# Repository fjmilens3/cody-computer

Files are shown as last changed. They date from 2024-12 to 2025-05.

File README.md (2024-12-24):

# The Cody Computer Project

This repository contains the design files and source code for the Cody 
Computer, an 8-bit home computer built around the WDC 65C02 and the 
Parallax Propeller.

Each subdirectory contains a portion of the design:

- `KiCad` contains the design files for the Cody Computer's electronics.
- `OpenSCAD` contains the design files for the Cody Computer's printable parts.
- `PDF` contains generated PDFs of the KiCad schematics.
- `Spin` contains the Propeller `.spin` files for the Propeller's firmware.
- `STL` contains the generated STL files suitable for slicing and printing.
- `Tass` contains the `64tass` assembly files for Cody BASIC and demo programs.
- `CodyBASIC` contains some sample Cody BASIC programs used for demo purposes.

All design files and sources are released under the GPL version 3. A mention
of the Cody Computer in any derived works is also appreciated.

__The Cody Computer Book__ detailing the project is not released under the GPL
but may be freely distributed. Visit 
[www.codycomputer.org](https://www.codycomputer.org) for more information.

If any technical issues or inaccuracies are found in any of the material,
please reach out to the author or raise an issue on GitHub.

Frederick John Milens III \
December 2024

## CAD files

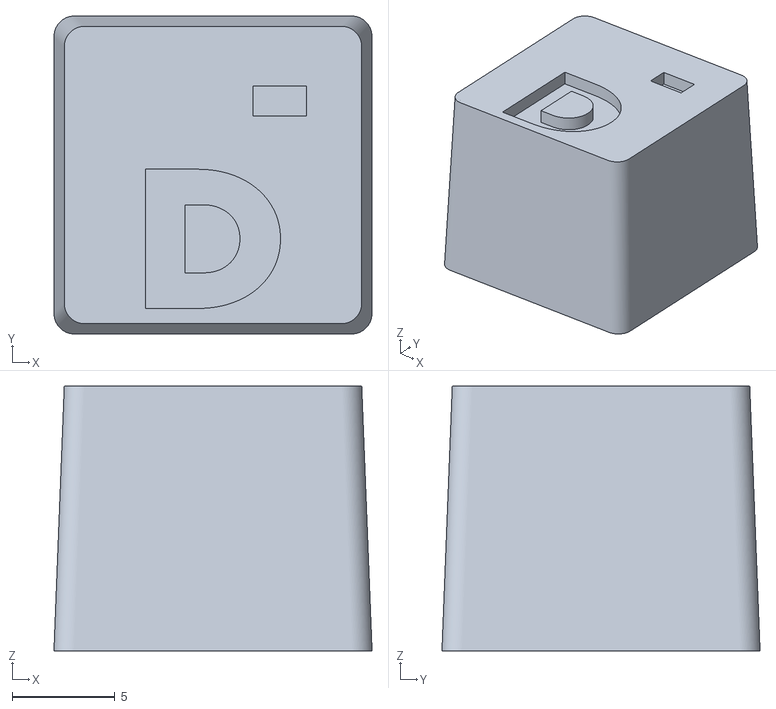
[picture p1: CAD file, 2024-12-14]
STL/KeycapD.stl
15.5 x 15.5 x 12.9

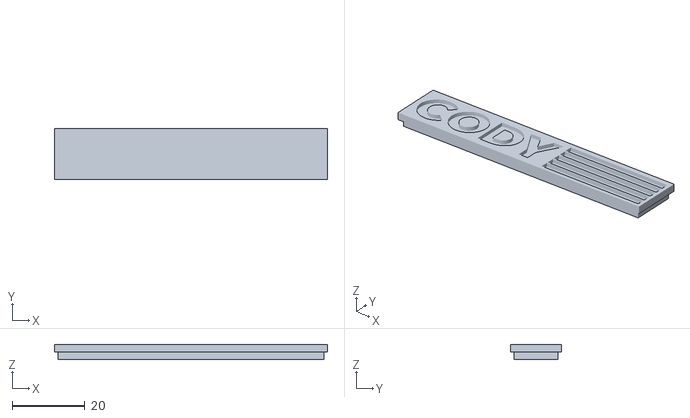
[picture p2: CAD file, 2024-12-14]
STL/CaseBadge.stl
75.0 x 14.0 x 4.00

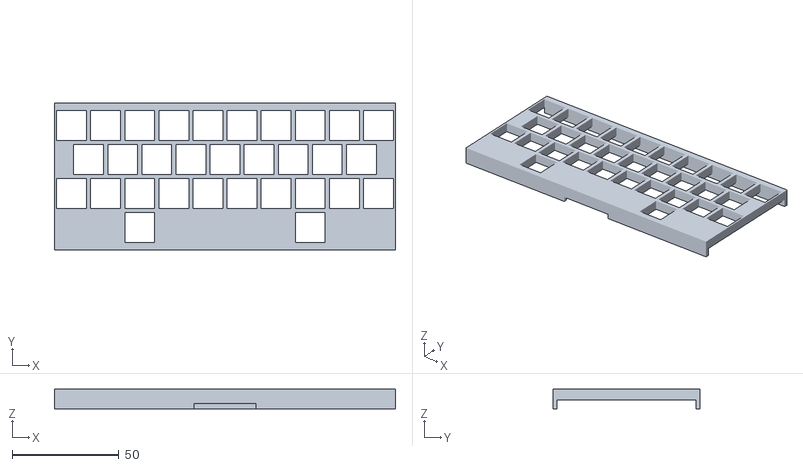
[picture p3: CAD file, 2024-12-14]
STL/KeyboardPlate.stl
160.0 x 69.0 x 9.20

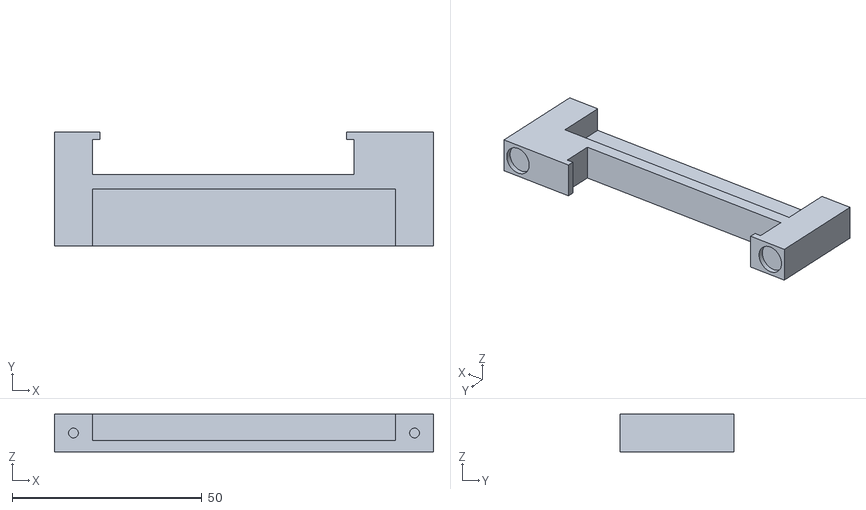
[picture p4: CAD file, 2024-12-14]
STL/KeyboardBracketWithoutHoles.stl
100.0 x 30.0 x 10.0

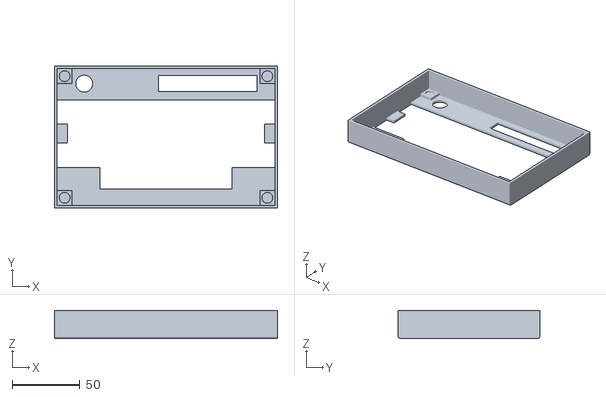
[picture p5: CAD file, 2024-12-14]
STL/CaseTop.stl
165.0 x 105.0 x 21.0

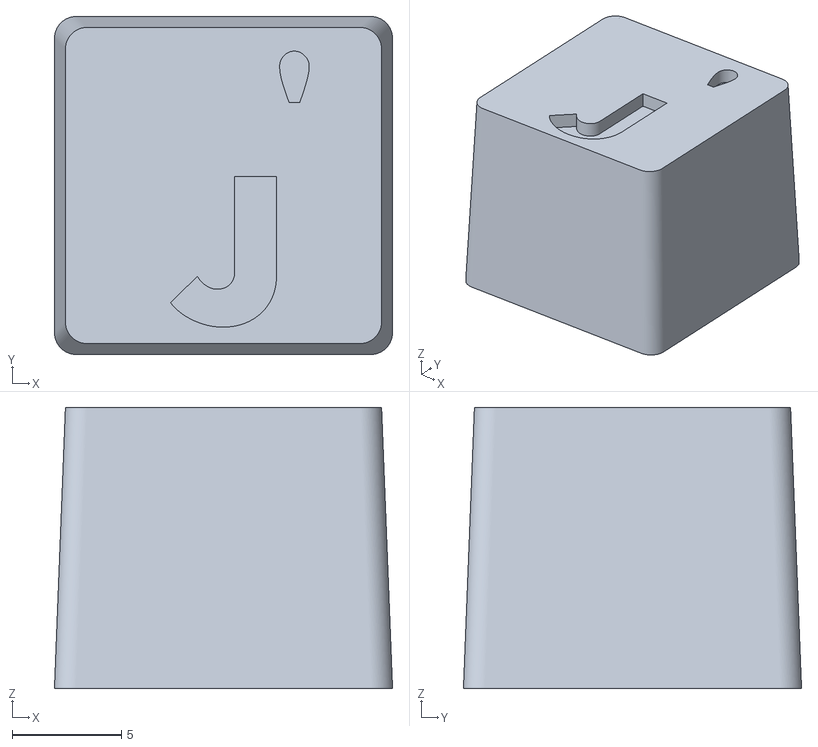
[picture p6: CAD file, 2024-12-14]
STL/KeycapJ.stl
15.5 x 15.5 x 12.9

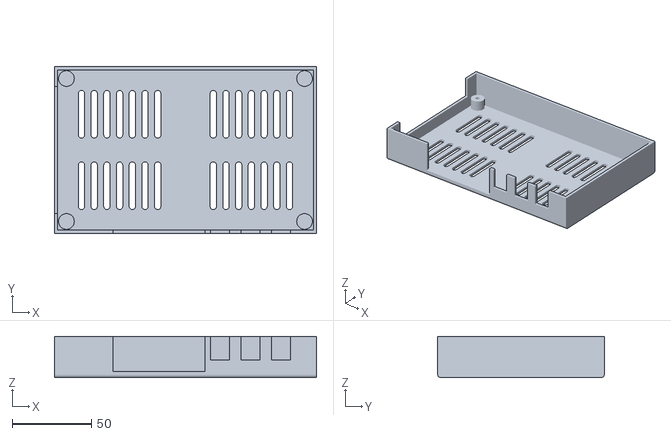
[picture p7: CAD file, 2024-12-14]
STL/CaseBottom.stl
165.0 x 105.0 x 26.0

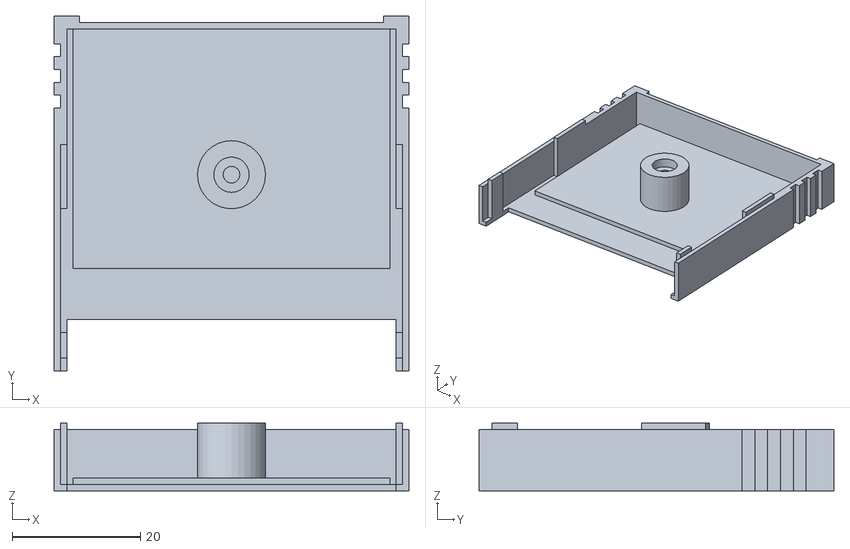
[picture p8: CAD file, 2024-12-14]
STL/CartridgeTop.stl
55.3 x 55.3 x 10.6

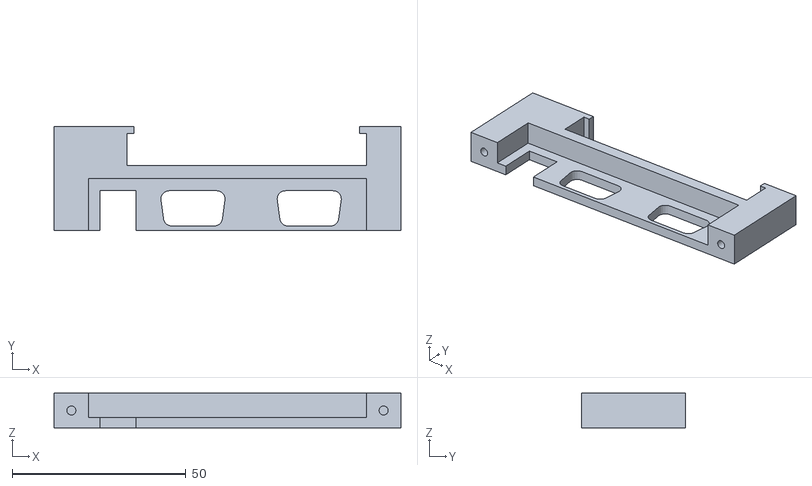
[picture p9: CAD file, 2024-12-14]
STL/KeyboardBracketWithHoles.stl
100.0 x 30.0 x 10.0

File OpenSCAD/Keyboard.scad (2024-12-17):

/*
 * Keyboard.scad
 * OpenSCAD file defining the keyboard for the Cody Computer (with the exception of the keycaps).
 *
 * Copyright 2024 Frederick John Milens III, The Cody Computer Developers.
 *
 * This program is free software; you can redistribute it and/or
 * modify it under the terms of the GNU General Public License
 * as published by the Free Software Foundation; either version 3
 * of the License, or (at your option) any later version.
 *
 * This program is distributed in the hope that it will be useful,
 * but WITHOUT ANY WARRANTY; without even the implied warranty of
 * MERCHANTABILITY or FITNESS FOR A PARTICULAR PURPOSE.  See the
 * GNU General Public License for more details.
 *
 * You should have received a copy of the GNU General Public License
 * along with this program; if not, write to the Free Software
 * Foundation, Inc., 51 Franklin Street, Fifth Floor, Boston, MA 02110-1301, USA.
 *
 * The Cody Computer's mechanical keyboard is designed for Cherry MX or compatible switches
 * and contains a total of 31 keys in four rows, including two keys used for a spacebar row.
 *
 * The Cody Computer's keyboard brackets form a major portion of the computer's assembly.
 * The bottom of the brackets mount to the top of the motherboard PCB using M3 screws and 
 * the keyboard plate slide-fits into notches in the top of the brackets.
 *
 * The brackets also provide some structural support for the case itself. The sides of the
 * brackets act as additional structural support for the walls of the case, and the tops of
 * the brackets hold magnets to connect to the interior top of the case.
 *
 * For the keyboard plate, space is provided for the PCB and a Dupont-style connector below 
 * the keyboard plate.
 */

module KeyboardPlate() {
    
    difference() {
        
        // keyboard plate
        cube([160, 69, 9.2]);
    
        // bottom cutout for PCB and component leads
        translate([0, 2, 0]) cube([160, 65, 4.2]);
        
        // keyboard row 1
        for (i = [0:9]) translate([1 + i * 16, 51.5, 0]) cube([14, 14, 20]);
     
        // keyboard row 2
        for (i = [0:8]) translate([9 + i * 16, 35.5, 0]) cube([14, 14, 20]);
          
        // keyboard row 3
        for (i = [0:9]) translate([1 + i * 16, 19.5, 0]) cube([14, 14, 20]);
    
        // space bar
        translate([33, 3.5, 0]) cube([14, 14, 20]);
        translate([113, 3.5, 0]) cube([14, 14, 20]);
        
        // empty region below spacebar for dupont connector leads (keyboard connector)
        translate([49, 3.5, 0]) cube([62, 14, 7.2]);
        
        // punchout in front for dupont connector plug (keyboard connector)
        translate([65.5, 0, 0]) cube([29, 10, 2.6]);
    }
}

module KeyboardBracketWithoutHoles() {
    
    difference () {
        
        // main bracket
        union() {
            
            difference() {
                
                // bracket rectangle
                cube([100, 30, 10]); // was 35mm high
            
                // top hole for keyboard plate press-fit
                translate([10, 30 - 9.2 - 2, 0]) cube([69, 9.2, 10]);
            
                // top hole for keyboard plate press-fit
                translate([12, 30 - 9.2, 0]) cube([65, 9.2, 10]);
            
                // bottom hole for components
                translate([10, 0, 0]) cube([80, 15, 10]); // was 20mm high
                               
                
            }
            
            // side panel
            translate([10, 0, 0]) cube([80, 15, 3]); // was 20 mm high
        }
        
        // M3 screw hole for left side of bracket
        translate([3.5, 20, 3.5]) translate([1.5, 0, 1.5]) rotate([90, 0, 0]) cylinder(h=20, d=2.6, $fn=50);
        
        // M3 screw hole for right side of bracket
        translate([93.5, 20, 3.5]) translate([1.5, 0, 1.5]) rotate([90, 0, 0]) cylinder(h=20, d=2.6, $fn=50);
        
        // magnet hole
        translate([1, 30, 1]) translate([4, 0, 4]) rotate([90, 0, 0]) cylinder(h=1.5, d=8.0, $fn=50);
       
        // magnet hole
        translate([91, 30, 1]) translate([4, 0, 4]) rotate([90, 0, 0]) cylinder(h=1.5, d=8.0, $fn=50); 
    }

}

module KeyboardBracketWithHoles() {

    difference() {
        
        translate([100, 0, 0]) mirror([1, 0, 0]) KeyboardBracketWithoutHoles();
        
        // joystick
        translate([30.55, 1.8]) DB9Hole();

        // joystick
        translate([64.06, 1.8]) DB9Hole();

        // power
        translate([13.2, 0]) cube([10.5, 11.5, 10]);
    }

}

module DB9Hole() {
    translate([9.5, 0]) hull() {
        translate([-6.85, 7.28]) cylinder(h=10, r=2.4, $fn=20);
        translate([6.85, 7.28]) cylinder(h=10, r=2.4, $fn=20);
        translate([-6.125, 1.9]) cylinder(h=10, r=2.4, $fn=20);
        translate([6.125, 1.9]) cylinder(h=10, r=2.4, $fn=20);
    }
}

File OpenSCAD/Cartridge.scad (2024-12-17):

/*
 * Cartridge.scad
 * OpenSCAD file defining the case for a Cody Computer cartridge.
 *
 * Copyright 2024 Frederick John Milens III, The Cody Computer Developers.
 *
 * This program is free software; you can redistribute it and/or
 * modify it under the terms of the GNU General Public License
 * as published by the Free Software Foundation; either version 3
 * of the License, or (at your option) any later version.
 *
 * This program is distributed in the hope that it will be useful,
 * but WITHOUT ANY WARRANTY; without even the implied warranty of
 * MERCHANTABILITY or FITNESS FOR A PARTICULAR PURPOSE.  See the
 * GNU General Public License for more details.
 *
 * You should have received a copy of the GNU General Public License
 * along with this program; if not, write to the Free Software
 * Foundation, Inc., 51 Franklin Street, Fifth Floor, Boston, MA 02110-1301, USA.
 *
 * The PCB mounts on the bottom portion of the cartridge, with the top
 * snapping in. A single screw is inserted from the back to the front
 * to hold the cartridge together.
 *
 * The bottom portion of the cartridge has a thin layer below the screw
 * hole. This acts as a bridge to avoid the need for supports and can
 * easily be removed by the screw itself (or a screwdriver) during
 * assembly.
 * 
 * Sanding will be required to ensure a snug fit between the cartridge
 * halves and the PCB.
 */
module CartridgeBottom() {
    
    difference () {
        
        // cartridge
        union() {
            
            difference() {
                
                // cartridge outer shell
                union() {
                    cube([55.340, 55.340, 7.6]);
                }
                
                // cartridge inner cavity
                translate([1, 0, 1]) cube([53.340, 53.340, 8.6]);
            }
        
            // thicker sections for ridges
            translate([0, 30.6 + 6.350, 0]) cube([2, 55.340 - (30.6 + 6.350), 7.6]);
            translate([53.340, 30.6 + 6.350, 0]) cube([2, 55.340 - (30.6 + 6.350), 7.6]);

            // stem for screw/PCB mount
            translate([26.670+1, 30.6, 0]) cylinder(h=5.0, d=10.6, $fn=32);
            translate([26.670+1, 30.6, 0]) cylinder(h=8.6, d=5.3, $fn=32);
            
            // bar for aligning PCB
            translate([10, 30.6 + 6.350, 0]) cube([35.340, 1, 6.6]);

            // tabs for aligning top and bottom of case
            translate([2, 52.340, 1]) cube([51.340, 1, 8.6]);
            translate([2, 30.6 + 6.350, 1]) cube([1, 53.340 - (30.6 + 6.350), 8.6]);
            translate([52.340, 30.6 + 6.350, 1]) cube([1, 53.340 - (30.6 + 6.350), 8.6]);
        }
        
        // Ridges
        translate([0, 49-8, 0]) cube([1, 2, 8.6]);
        translate([0, 49-4, 0]) cube([1, 2, 8.6]);
        translate([0, 49, 0]) cube([1, 2, 8.6]);
        
        translate([54.340, 49-8, 0]) cube([1, 2, 8.6]);
        translate([54.340, 49-4, 0]) cube([1, 2, 8.6]);
        translate([54.340, 49, 0]) cube([1, 2, 8.6]);
        
        // Label slot
        translate([4, 54.340, 2]) cube([47.340, 1, 5.6]);
        
        // M3 screw hole (for self-tapping screw)
        // Has a small amount of material as a bridge to avoid supports
        translate([26.670+1, 30.6, 2.6]) cylinder(h=8, d=2.6, $fn=32);
        translate([26.670+1, 30.6, 0]) cylinder(h=2.4, d=6.5, $fn=32);
    }
}

module CartridgeTop() {
    
    difference () {
        
        // cartridge
        union() {
            
            difference() {
                
                // cartridge outer shell
                cube([55.340, 55.340, 9.6]);
                
                // cartridge inner cavity
                translate([1, 0, 1]) cube([53.340, 53.340, 9.6]);   
            }
            
            // thicker sections for ridges
            translate([0, 30.6 + 6.350 - 2, 0]) cube([2, 55.340 - (30.6 + 6.350) + 2, 9.6]);
            translate([53.340, 30.6 + 6.350 - 2, 0]) cube([2, 55.340 - (30.6 + 6.350) + 2, 9.6]);
            
            // side stabilizers
            translate([1, 30.6 - 5.3, 0]) cube([1, 10, 10.6]);
            translate([53.340, 30.6 - 5.3, 0]) cube([1, 10, 10.6]); 
            
            translate([1, 2, 0]) cube([1, 4, 10.6]);
            translate([53.340, 2, 0]) cube([1, 4, 10.6]); 
                        
            // thicker area for label recess
            translate([3, 16, 0]) cube([49.340, 38.34, 2]);
            
            // stem for screw/PCB mount
            translate([26.670+1, 30.6, 0]) cylinder(h=10.6, d=10.6, $fn=32);
        }
        
        // Hole for exposed pins
        translate([2, 0, 0]) cube([51.340, 8, 3]);  
        
        // Ridges
        translate([0, 49-8, 0]) cube([1, 2, 10.6]);
        translate([0, 49-4, 0]) cube([1, 2, 10.6]);
        translate([0, 49, 0]) cube([1, 2, 10.6]);
        
        translate([54.340, 49-8, 0]) cube([1, 2, 10.6]);
        translate([54.340, 49-4, 0]) cube([1, 2, 10.6]);
        translate([54.340, 49, 0]) cube([1, 2, 10.6]);
        
        // Label slots
        translate([4, 54.340, 0]) cube([47.340, 1, 9.6]);
        translate([4, 18, 0]) cube([47.340, 40.340, 1]);
        
        // M3 screw hole (for self-tapping screw)
        translate([26.670+1, 30.6, 3.6]) cylinder(h=6, d=2.6, $fn=32);
        
        // Post hole (for post on other part)
        translate([26.670+1, 30.6, 8.6]) cylinder(h=2, d=5.5, $fn=32);
    }
}

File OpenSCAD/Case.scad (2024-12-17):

/*
 * Case.scad
 * OpenSCAD file defining the case for the Cody Computer.
 *
 * Copyright 2024 Frederick John Milens III, The Cody Computer Developers.
 *
 * This program is free software; you can redistribute it and/or
 * modify it under the terms of the GNU General Public License
 * as published by the Free Software Foundation; either version 3
 * of the License, or (at your option) any later version.
 *
 * This program is distributed in the hope that it will be useful,
 * but WITHOUT ANY WARRANTY; without even the implied warranty of
 * MERCHANTABILITY or FITNESS FOR A PARTICULAR PURPOSE.  See the
 * GNU General Public License for more details.
 *
 * You should have received a copy of the GNU General Public License
 * along with this program; if not, write to the Free Software
 * Foundation, Inc., 51 Franklin Street, Fifth Floor, Boston, MA 02110-1301, USA.
 *
 * The bottom portion of the case is affixed via screws to the keyboard mounting
 * brackets specified in a separate file. Refer to that file and the assembly
 * instructions for more information.
 *
 * The top portion of the case is magnetically attached to the top of the keyboard
 * mounting brackets for easy removal (and exploration!). The case badge and LED
 * holder also glue or press-fit into the top of the case.
 *
 * For the case badge the CODY name is recessed into the badge using an SVG file.
 * These spaces can be filled with air-dry clay similar to the keycaps. Slots for
 * color (or painted) inlays are also provided, giving an aesthetic similar to many
 * 1980s computer cases.
 */

module CaseTop() {

    difference() {
    
        union() {
    
            // bottom with cavity
            difference () {
                
                // main shape
                hull() {
                    translate([0, 2, 2]) rotate([0, 90, 0]) cylinder(h=165, r=2, $fn=20);
                    translate([0, 103, 2]) rotate([0, 90, 0]) cylinder(h=165, r=2, $fn=20);
                    translate([0, 0, 20]) cube([165, 105, 1]);
                }
                
                // interior
                translate([2, 2, 2]) cube([161, 101, 19]);
                
                // keyboard punchout
                translate([2.5, 14, 0]) translate([80, 9, 15]) union() {
                    
                    // space bar punchout
                    translate([0, 0, 0]) cube([96 + 2, 16 + 2, 30], center=true);
                    
                    // keyboard row 3 punchout
                    translate([0, 16, 0]) cube([160 + 1, 16 + 2, 30], center=true);
                    
                    // keyboard row 2 punchout
                    translate([0, 32, 0]) cube([144 + 2, 16 + 2, 30], center=true);
                    
                    // keyboard row 3 punchout
                    translate([0, 48, 0]) cube([160 + 1, 16 + 2, 30], center=true);
                
                }
    
                DELTA = 2;
                
                // decorative grooves
                translate([2, 97 + DELTA, 0]) cube([161, 2, 1]);
                translate([2, 93 + DELTA, 0]) cube([161, 2, 1]);
                translate([2, 89 + DELTA, 0]) cube([161, 2, 1]);
                translate([2, 85 + DELTA, 0]) cube([161, 2, 1]);
                translate([2, 81 + DELTA, 0]) cube([161, 2, 1]);
        
            }
    
            // magnet bosses
            translate([2.5 + 5, 2.5 + 5, 2]) MagnetBoss();
            translate([2.5 + 5, 2.5 + 5 + 90, 2]) MagnetBoss();
            translate([2.5 + 5 + 150, 2.5 + 5, 2]) MagnetBoss();
            translate([2.5 + 5 + 150, 2.5 + 5 + 90, 2]) MagnetBoss();
       
            // LED holder mount ring
            translate([22, 81+11, 0.5]) cylinder(h=1, d=13.5, center=true, $fn=50);
    
            // badge mount outline    
            translate([165 - 15 - 73 - 0.5, 84+2 - 0.5, 0]) cube([74, 13, 1]);
        }

        // LED holder mount
        translate([22, 81+11, 0]) cylinder(h=10, d=12.5, center=true, $fn=50);
    
        // badge mount        
        translate([165 - 15 - 73, 84+2, 0]) cube([73, 12, 2]);
    }
}

module CaseBottom() {

    difference() {
    
        union() {
    
            // bottom with cavity
            difference () {
                
                // main shape
                hull() {
                
                    translate([0, 2, 2]) rotate([0, 90, 0]) cylinder(h=165, r=2, $fn=20);
                
                    translate([0, 103, 2]) rotate([0, 90, 0]) cylinder(h=165, r=2, $fn=20);
                    
                    translate([0, 0, 25]) cube([165, 105, 1]);
            
                }
            
                // interior
                translate([2, 2, 2]) cube([161, 101, 25]);
        
            }
    
            // PCB mounting standoffs
            translate([2.5 + 5, 2.5 + 5, 0]) cylinder(h=9.63, d=10, $fn=20);
            translate([2.5 + 5, 2.5 + 5 + 90, 0]) cylinder(h=9.63, d=10, $fn=20);
            translate([2.5 + 5 + 150, 2.5 + 5, 0]) cylinder(h=9.63, d=10, $fn=20);
            translate([2.5 + 5 + 150, 2.5 + 5 + 90, 0]) cylinder(h=9.63, d=10, $fn=20);
        }
        
        // screw heads
        translate([2.5 + 5, 2.5 + 5, 0]) cylinder(h=7.63, d=6.5, $fn=20);
        translate([2.5 + 5, 2.5 + 5 + 90, 0]) cylinder(h=7.63, d=6.5, $fn=20);
        translate([2.5 + 5 + 150, 2.5 + 5, 0]) cylinder(h=7.63, d=6.5, $fn=20);
        translate([2.5 + 5 + 150, 2.5 + 5 + 90, 0]) cylinder(h=7.63, d=6.5, $fn=20);
    
        // screw holes (gives a couple of layers to punch out rather than using supports)
        translate([2.5 + 5, 2.5 + 5, 7.63 + 0.20]) cylinder(h=10, d=3.1, $fn=20);
        translate([2.5 + 5, 2.5 + 5 + 90, 7.63 + 0.20]) cylinder(h=10, d=3.1, $fn=20);
        translate([2.5 + 5 + 150, 2.5 + 5, 7.63 + 0.20]) cylinder(h=10, d=3.1, $fn=20);
        translate([2.5 + 5 + 150, 2.5 + 5 + 90, 7.63 + 0.20]) cylinder(h=10, d=3.1, $fn=20);
    
        // vent holes
        for(count = [0 : 6]) {
            translate([15 + count * 8, 15, 0]) VentHole();
            translate([15 + count * 8, 105 - 15 - 30, 0]) VentHole();
            translate([165 - 15 - 4 - count * 8, 15, 0]) VentHole();
            translate([165 - 15 - 4 - count * 8, 105 - 15 - 30, 0]) VentHole();
        }
        
        // expansion port
        translate([2.5 + 34.2, 0, 4]) cube([58, 10, 17 + 10]);
        
        // video port
        translate([2.5 + 95.7, 0, 11.23]) cube([12, 10, 17]);
        
        // audio port
        translate([2.5 + 114.9, 0, 11.23]) cube([12, 10, 17]);
    
        // prop plug port
        translate([2.5 + 134.1, 0, 11.23]) cube([12, 10, 17]);
        
        // side panel
        translate([0, 10 + 2.5, 11.23]) cube([5, 80, 15]);
    }
}

module LEDHolder() {

    difference() {
            
        union() {
            
            difference() {
            
                union() {
                    
                    // top ring
                    translate([0, 0, 4]) cylinder(h=2, d=14, center=true, $fn=50);
            
                    // main body
                    cylinder(h=10, d=12, center=true, $fn=50);
                }
                
                // hole for LED
                cylinder(h=10, d=11, center=true, $fn=50); // was 11
            
            }
        
            // bottom ring
            translate([0, 0, -6]) cylinder(h=2, d=12, center=true, $fn=50);
        
        }
    
        // LED lead holes
        cylinder(h=40, d=7, center=true, $fn=50);
    }   
}

module CaseBadge() {
    
    difference() {

        // Shape for the main badge (including lower part that pops into top of case)
        union() {
            cube([75, 14, 2]);    
            translate([1, 1, -2]) cube([73, 12, 2]);
        }
        
        // Slots for color inlays
        for (i = [0:4]) {
            translate([44, 1 + 2.4*i, 1]) cube([30, 2, 1]);
        }

        // CODY legend
        translate([1, 1, 1]) linear_extrude(2) import("./SVG/CodyLabel.svg", center=false);
    }    
}

module CaseBadgeInlay() {

    cube([30 - 0.2, 2 - 0.2, 1.6]);
}

module MagnetBoss() {
 
    difference () {
        
        // boss
        translate([0, 0, 2.3/2]) cube([11, 11, 2.3], center=true);

        // hole
        translate([0, 0, 0.8]) cylinder(h=1.5, d=8.0, $fn=50);
    }
}

module VentHole() {

    translate([0, 2, 0]) hull() {
        
        translate([2, 0, 0]) cylinder(h=10, d=4, $fn=20);
        translate([2, 26, 0]) cylinder(h=10, d=4, $fn=20);
    }
}

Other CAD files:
STL/KeycapP.stl
STL/KeycapI.stl
STL/KeycapCody.stl
STL/KeycapB.stl
STL/KeycapK.stl
STL/KeycapE.stl
STL/KeycapW.stl
STL/KeycapO.stl
STL/KeycapArrow.stl
OpenSCAD/Keycap.scad
OpenSCAD/Keychain.scad
STL/CartridgeBottom.stl
STL/CaseBadgeInlay.stl
STL/KeycapA.stl
STL/KeycapC.stl
STL/KeycapF.stl
STL/KeycapG.stl
STL/KeycapH.stl
STL/KeycapL.stl
STL/KeycapM.stl
STL/KeycapMeta.stl
STL/KeycapN.stl
STL/KeycapQ.stl
STL/KeycapR.stl
STL/KeycapS.stl
STL/KeycapT.stl
STL/KeycapU.stl
STL/KeycapV.stl
STL/KeycapX.stl
STL/KeycapY.stl
STL/KeycapZ.stl
STL/Keychain.stl
STL/LEDHolder.stl
STL/Spacebar.stl

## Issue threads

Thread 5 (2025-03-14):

Avoid cartridge reload when returning from binary programs

fjmilens3, 2025-03-14:
@dgelessus has been working on some assembly language programming from within Cody BASIC and noted that the current behavior when returning from a cartridge program isn't ideal.

The current implementation calls into `MAIN` when returning from any binary program, either loaded via serial or via cartridge. This provides more of a "clean slate" for binary programs loaded from BASIC but also introduces some problems, particularly for cartridges being used as any kind of expansion. Cartridges get stuck in a loop where the cartridge-detect re-runs and reloads the cartridge rather than returning to BASIC.

fjmilens3, 2025-03-16:
Should be resolved by #6.

Closed 2025-03-16.

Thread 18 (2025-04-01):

Optimize row effects to reduce on-screen blinking and glitching

fjmilens3, 2025-04-01:
In certain situations I'm seeing glitching/blinking when large numbers of sprites are displayed using row effects.

These hadn't shown up earlier so I suspect something has changed to throw the timing off just a bit. When I modify the Propeller firmware in an ad-hoc fashion to have fewer row effects the problem goes away, so it's right on the threshold of *not* being a problem.

The easiest way to get a few extra cycles' worth of margin is to not read *all* row effects on each scanline. The current implementation is nice from the standpoint of simplicity but it does waste a lot of cycles reading each entry in the row effects tables. A better solution would be to keep the last row effect index and start reading from that one on the next line.

Closed 2025-04-02.

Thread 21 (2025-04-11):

BASIC REPL overwrites zero page variable `SYS_A` (`PEEK(0)`)

dgelessus, 2025-04-11:
Since the recent firmware updates, it seems that the `SYS_A` zero page variable is not preserved anymore when using BASIC interactively.

For example, if I interactively run `POKE 0, 123` and then `PRINT PEEK(0)`, it prints `75` instead of `123`. The same thing with address 1 instead of 0 works correctly.

Similarly, if I load a very simple assembly program into memory:

```test_call:
	lda #12
	ldx #34
	ldy #56
	rts
```

and call it interactively using (e. g.) `SYS 25600` and then print out the values at addresses 0, 1, and 2, it shows **`75`**, `34`, `56` - i. e. the value from the A register is lost, but the values from the X and Y registers are correctly preserved.

The bug only affects the interactive BASIC REPL. If I do the same tests in a BASIC *program*, they work fine. For example, this correctly prints `123`:

```
10 POKE 0, 123
20 PRINT PEEK(0)
```

So this is not a major problem for complete programs, but it is quite confusing and impractical when debugging a `SYS` call interactively.

I assume the bug is related to the changes in 6627795f2bc24a74d637ba89264c6db6992c629d, because `SYS_A` is now used as a temporary variable during tokenizing.

Closed 2025-04-16.

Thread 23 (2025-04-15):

Nice to have: BASIC should preserve lowercase in comments

dgelessus, 2025-04-15:
Currently, Cody BASIC converts comment text to uppercase, just like keywords and variable names. For example, typing this:

```basic
10 REM Comment
LIST
```

shows

```basic
10 REM COMMENT
```

i. e. the mixed-case `Comment` was converted to all uppercase `COMMENT`. It would be nice if capitalization in `REM` text was preserved, like it already is in string literals.

dgelessus, 2025-04-15:
As a workaround, if you *really really* need lowercase in a comment for some reason, double-quoted text in a comment also has its capitalization preserved. So this works for example:

```basic
10 REM "Comment"
LIST
```

shows

```basic
10 REM "Comment"
```

fjmilens3, 2025-04-16:
Note: This, combined with the other issue we talked about, likely indicates a bigger issue as content after a `REM` token should be copied verbatim as an optimization (why tokenize comments?).

Closed 2025-04-17.

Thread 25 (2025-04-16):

Text containing `AB` freezes the BASIC tokenizer

fjmilens3, 2025-04-16:
@dgelessus has discovered that entering otherwise-random text containing `AB` or `AA` into the tokenizer causes Cody BASIC to lock up.

Funnily enough, the word "DISABLE" actually caused the issue to show up for the first time. :smile:

I've looked into it and I think the cause is related to the binary search implementation in the tokenizer. The "lowest" token in alphabetical order is `ABS`.

https://github.com/fjmilens3/cody-computer/blob/80582e6d2b405b3a6b13cd8e036f7fa05daaf825/Tass/codybasic.asm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

As part of the binary search, when we find an incoming token that is "lower" than the current pivot, we go to the lower half/partition. However, since the incoming token is even "lower" than the lowest value, we'll keep decrementing.

https://github.com/fjmilens3/cody-computer/blob/80582e6d2b405b3a6b13cd8e036f7fa05daaf825/Tass/codybasic.asm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

We should catch that as part of our test at the beginning of each loop, but because we wrap around from `$00` to `$FF`, the comparison passes and we incorrectly proceed after a wraparound.

https://github.com/fjmilens3/cody-computer/blob/80582e6d2b405b3a6b13cd8e036f7fa05daaf825/Tass/codybasic.asm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

Note that this explains why `AA` and `AB` cause the problem but `AC` does not.

A lot of that binary search/tokenization code was a hack to speed up loading BASIC program over serial, and I don't like it. However, in this case the quickest fix is checking whether or not we wrapped around (i.e. `TOKENIZER` value of `$FF`).

Closed 2025-04-17.

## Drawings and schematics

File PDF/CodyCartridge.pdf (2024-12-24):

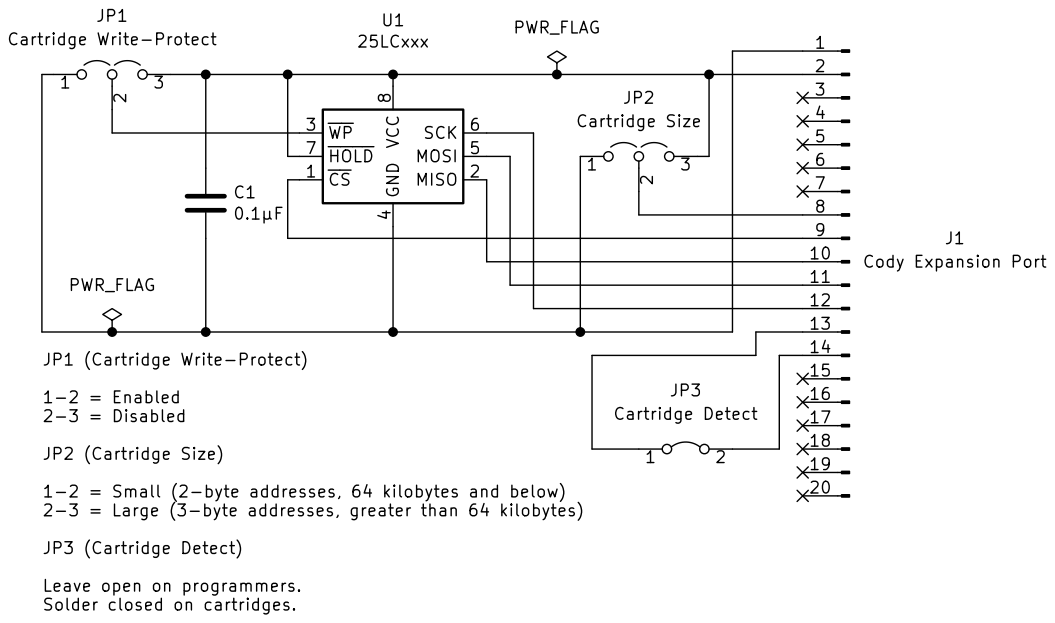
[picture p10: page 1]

4 MOSI 5 SCK 6 ~{HOLD} 7 VCC

JP1 (Cartridge Write-Protect) 1-2 = Enabled

1-2 = Small (2-byte addresses, 64 kilobytes and below)
2-3 = Large (3-byte addresses, greater than 64 kilobytes)

Leave open on programmers.
Solder closed on cartridges.

File: CodyCartridge.kicad_sch Sheet: /
Id: 1/1 Title: Cody Cartridge

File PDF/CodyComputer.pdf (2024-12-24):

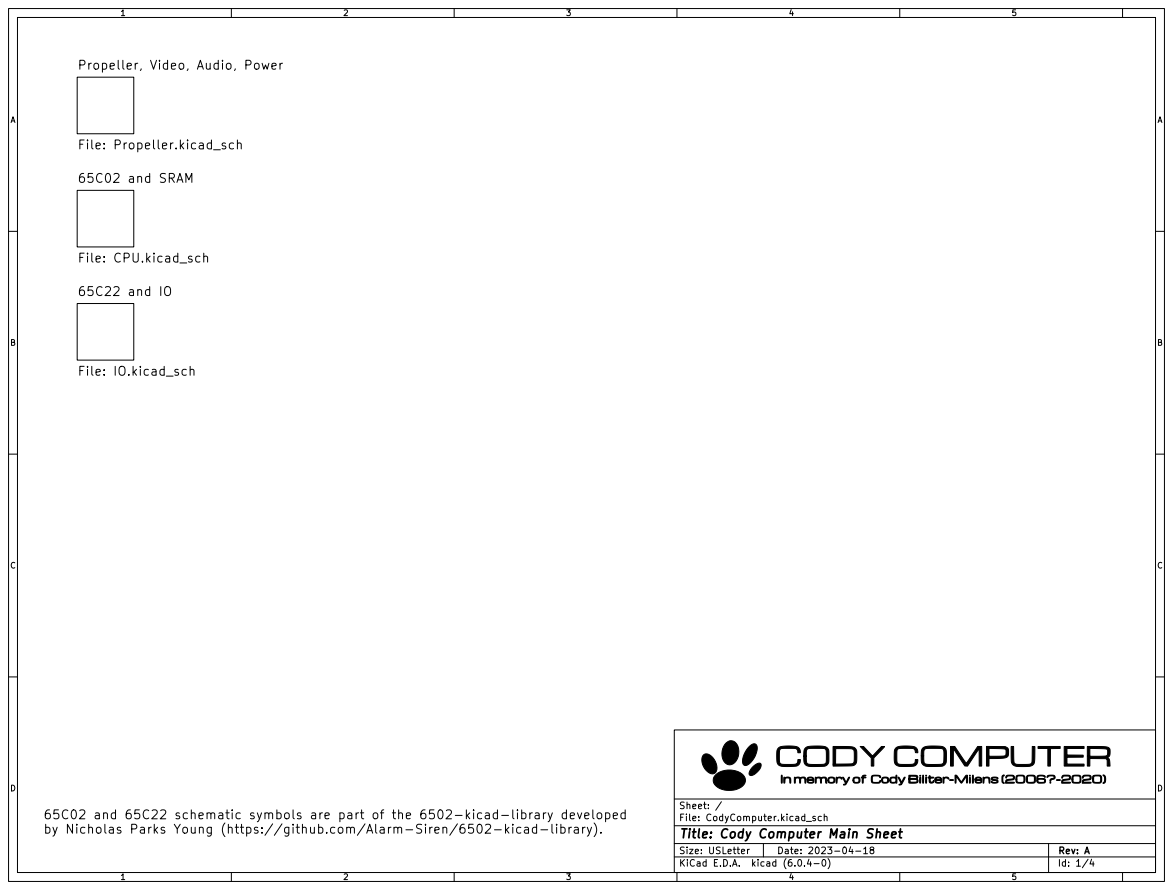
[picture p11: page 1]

Propeller, Video, Audio, Power

65C02 and 65C22 schematic symbols are part of the 6502-kicad-library developed
by Nicholas Parks Young (https://github.com/Alarm-Siren/6502-kicad-library).

File: CodyComputer.kicad_sch Sheet: /
Id: 1/4 Title: Cody Computer Main Sheet

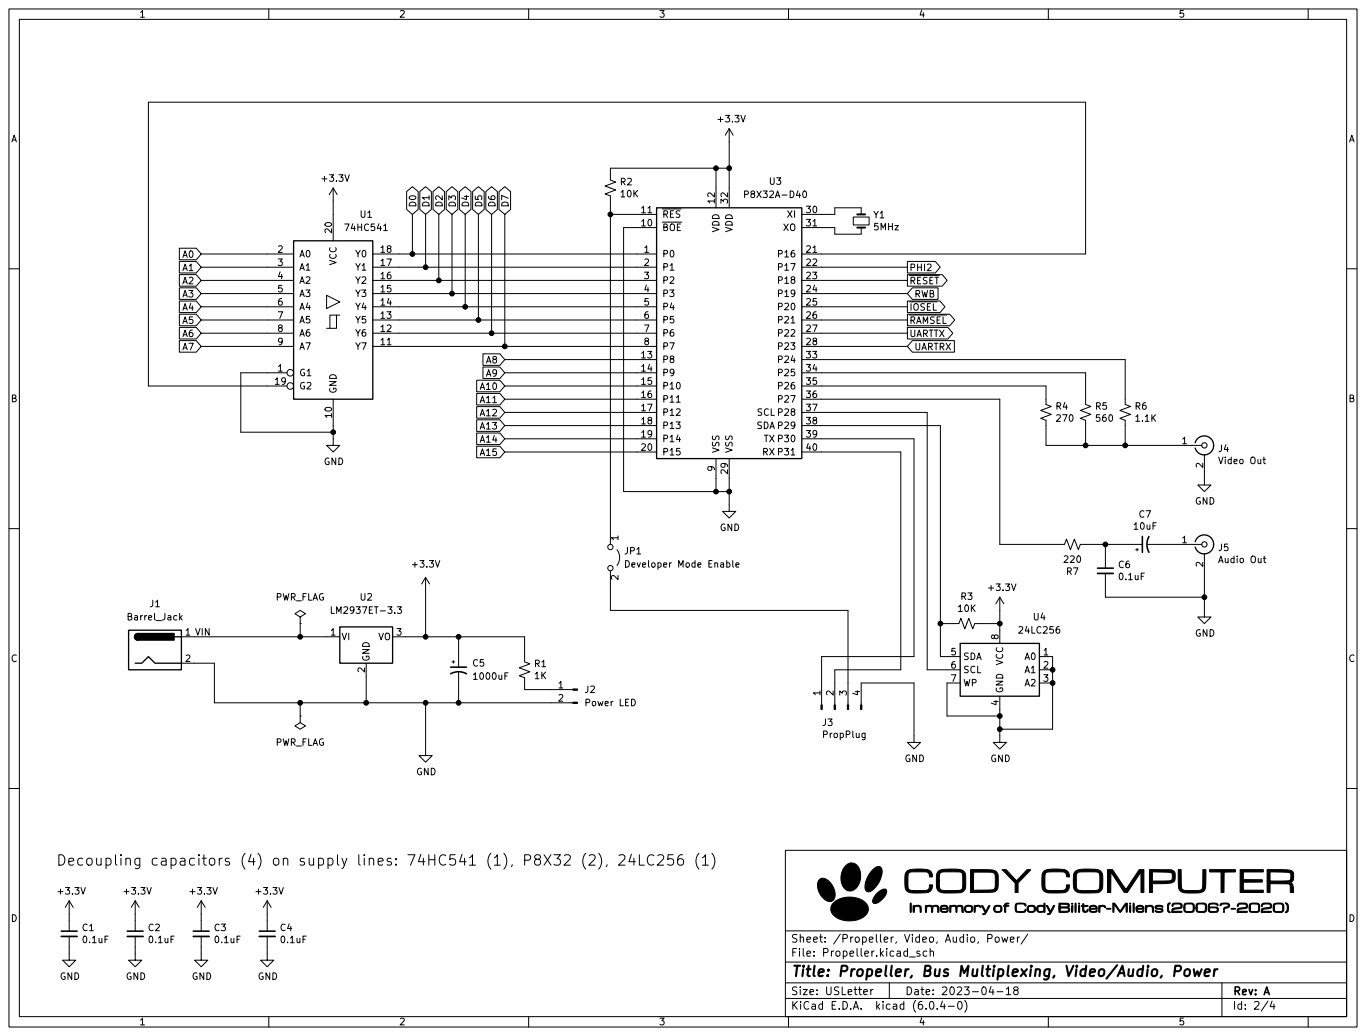
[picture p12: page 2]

4 SDA 5 SCL 6 WP 7 VCC

Sheet: /Propeller, Video, Audio, Power/
File: Propeller.kicad_sch
Id: 2/4 Title: Propeller, Bus Multiplexing, Video/Audio, Power

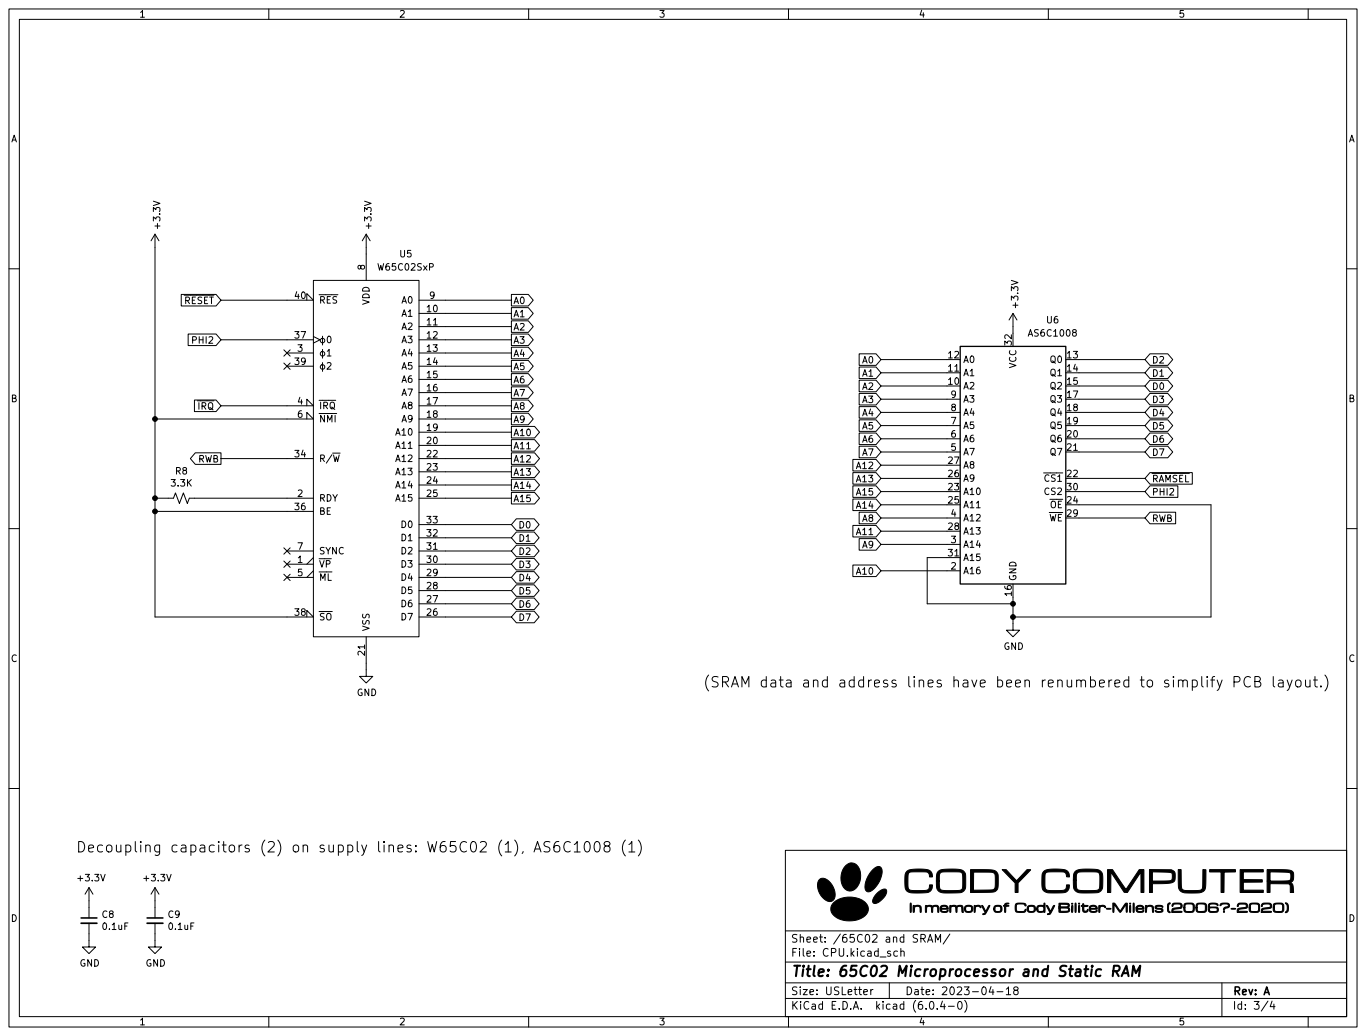
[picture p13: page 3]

(SRAM data and address lines have been renumbered to simplify PCB layout.)

Id: 3/4 Title: 65C02 Microprocessor and Static RAM

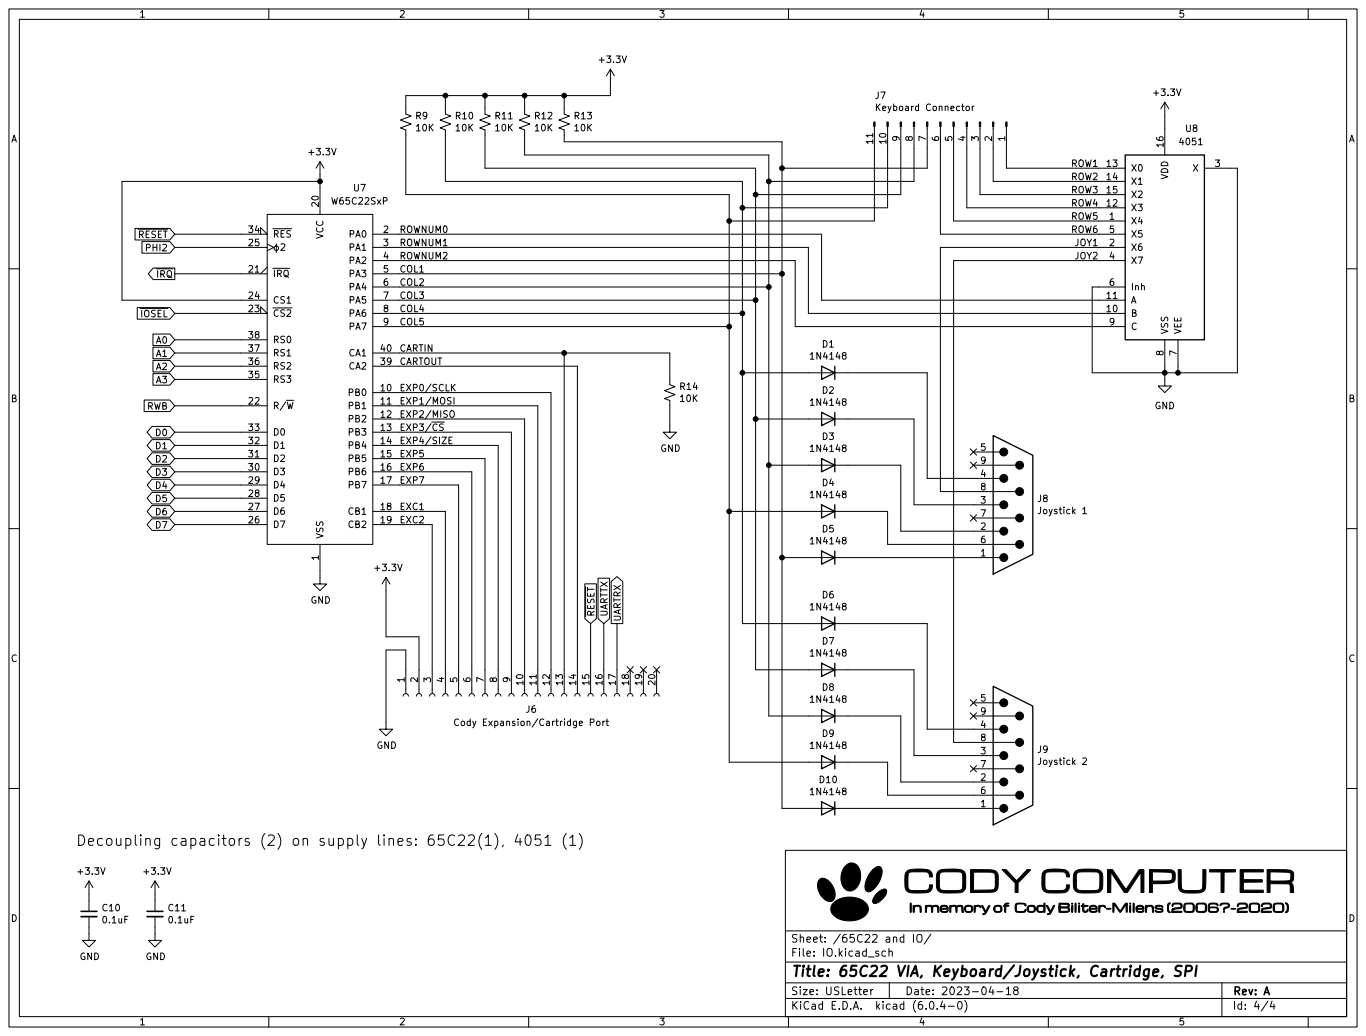
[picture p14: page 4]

JOY1 Decoupling capacitors (2) on supply lines: 65C22(1), 4051 (1)

J6 Cody Expansion/Cartridge Port

File: IO.kicad_sch Sheet: /65C22 and IO/ GND

Id: 4/4 Title: 65C22 VIA, Keyboard/Joystick, Cartridge, SPI

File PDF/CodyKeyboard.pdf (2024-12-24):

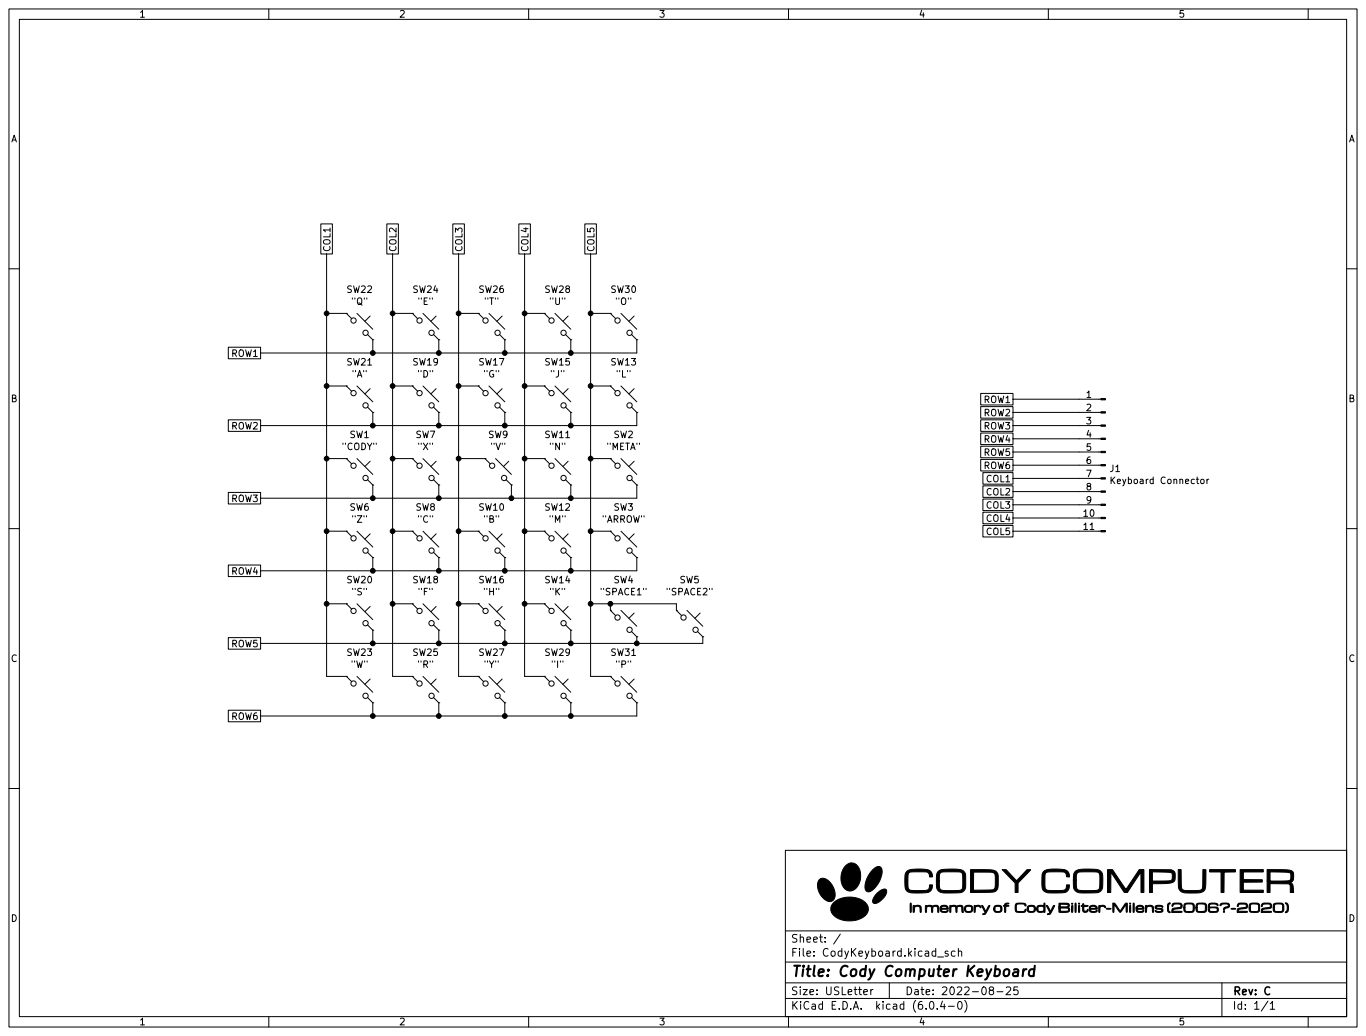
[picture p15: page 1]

Id: 1/1 Title: Cody Computer Keyboard

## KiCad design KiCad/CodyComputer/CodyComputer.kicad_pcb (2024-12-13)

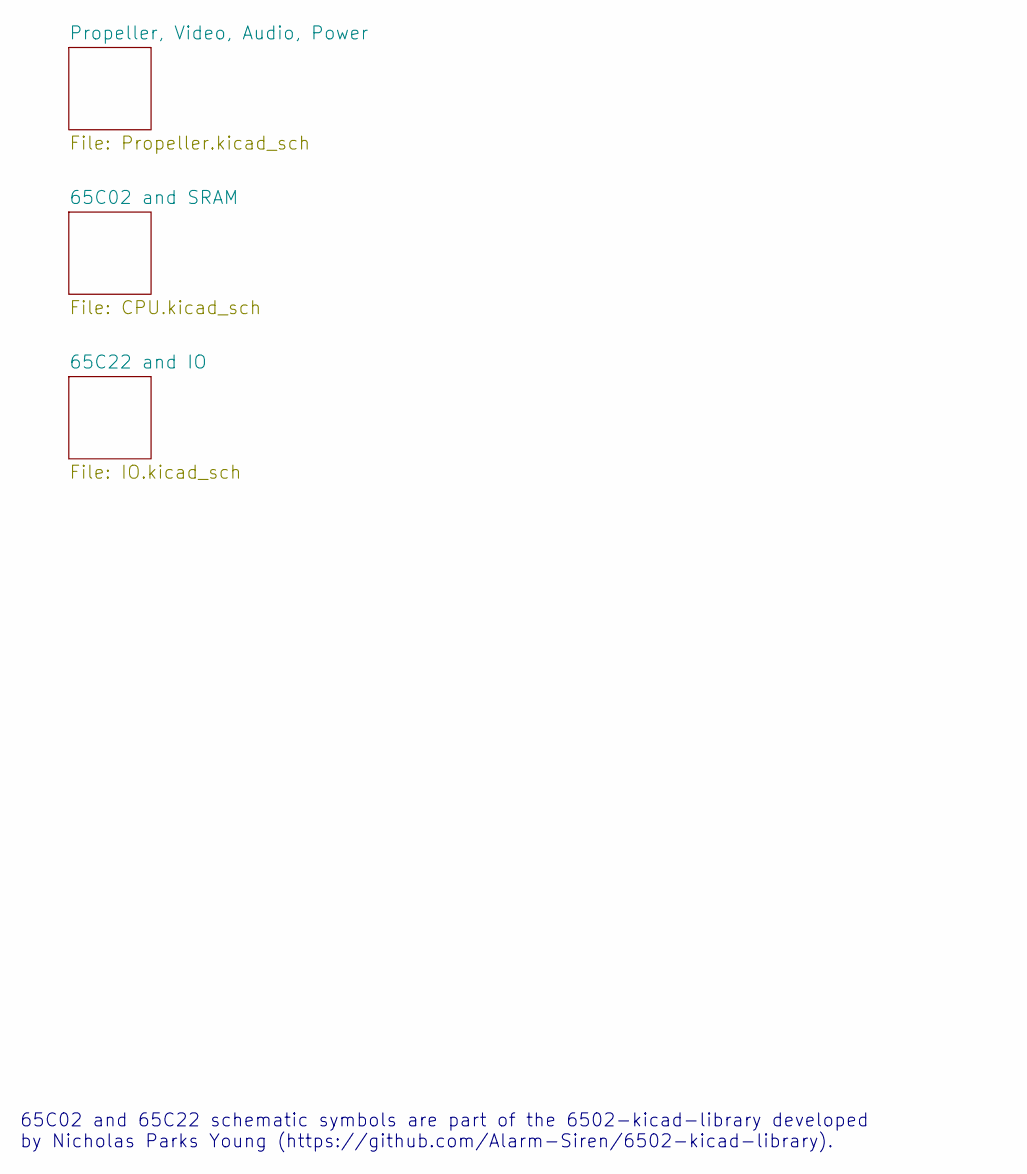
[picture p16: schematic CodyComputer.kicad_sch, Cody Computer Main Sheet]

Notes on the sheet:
65C02 and 65C22 schematic symbols are part of the 6502-kicad-library developed by Nicholas Parks Young (https://github.com/Alarm-Siren/6502-kicad-library).

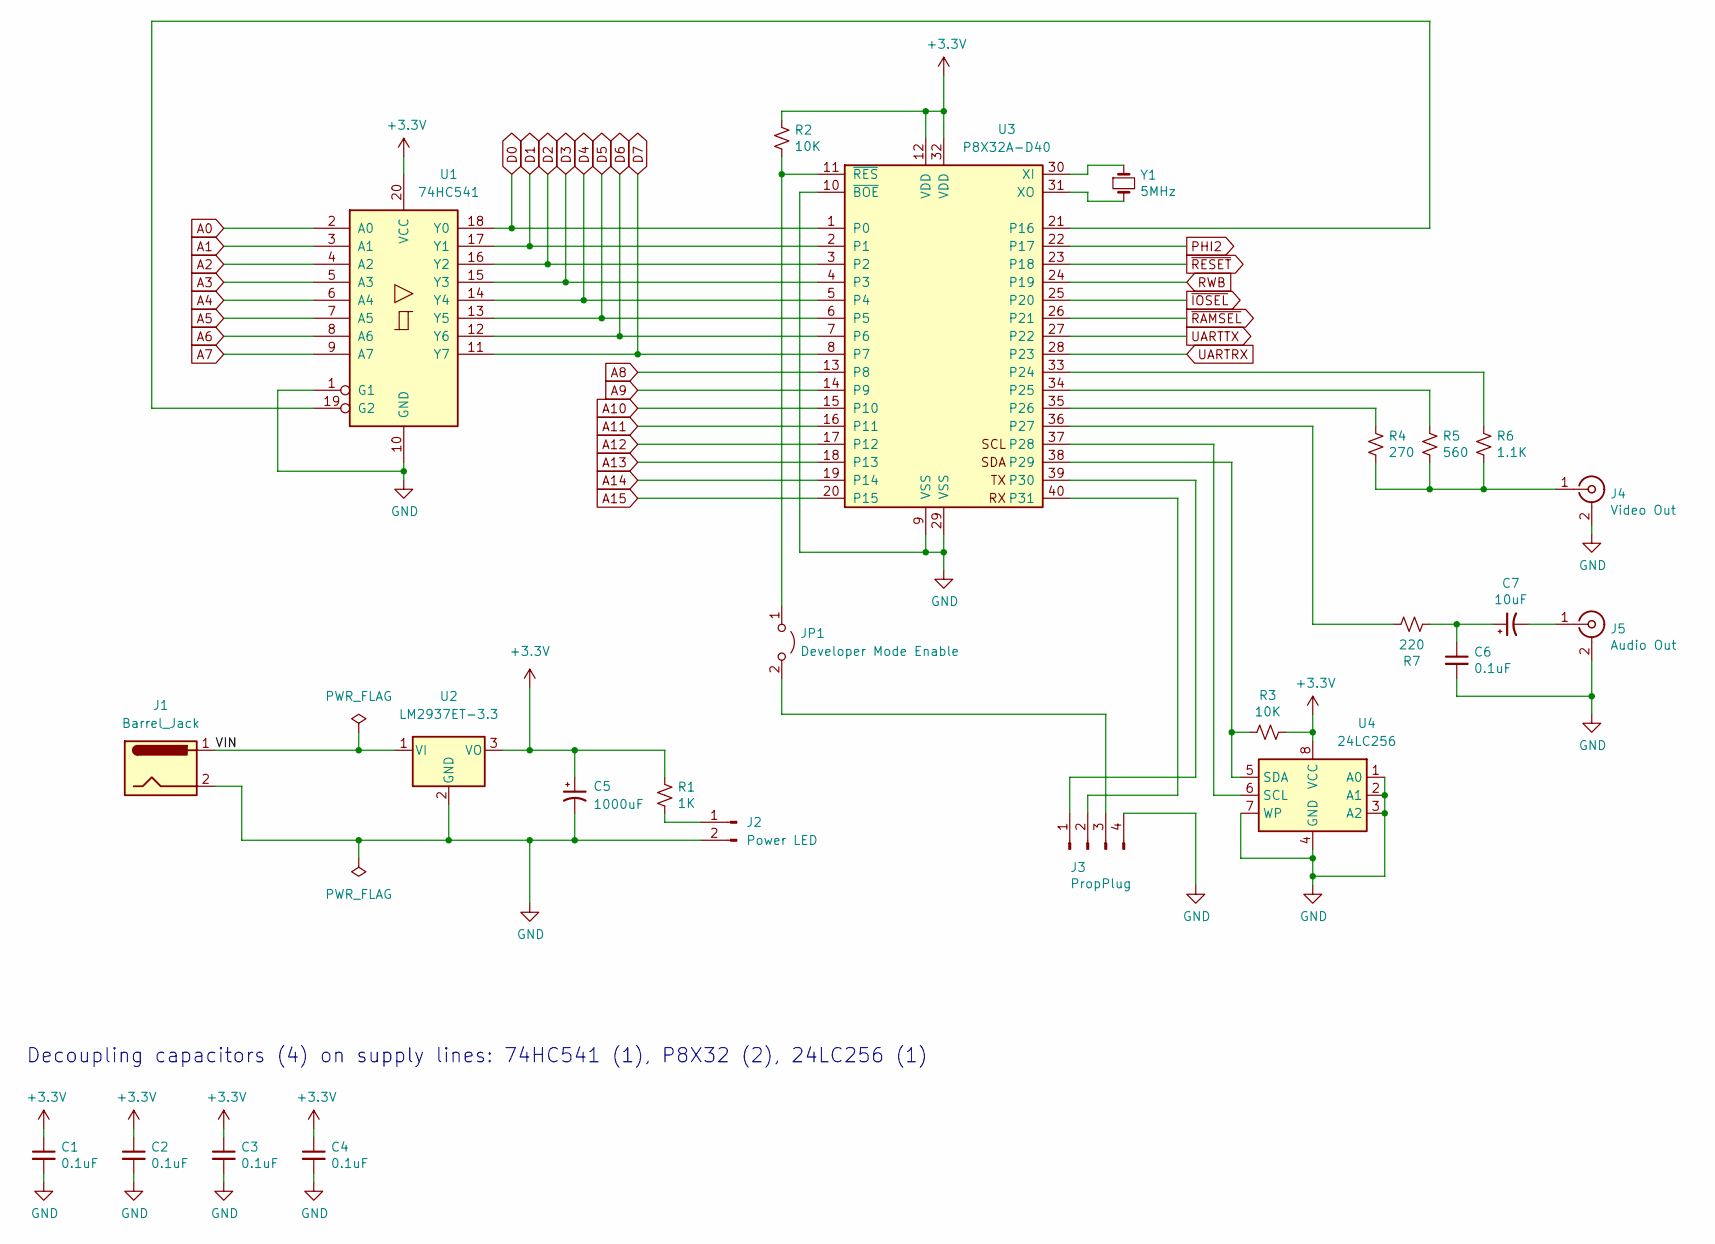
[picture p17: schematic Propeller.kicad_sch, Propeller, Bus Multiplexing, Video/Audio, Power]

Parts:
C1, C2, C3, C4, C6: 0.1uF; C_Disc_D3.8mm_W2.6mm_P2.50mm
C5: 1000uF; CP_Radial_D8.0mm_P3.50mm
C7: 10uF; CP_Radial_D5.0mm_P2.00mm
J1: Barrel_Jack; BarrelJack_Horizontal
J2: Power LED; PinHeader_1x02_P2.54mm_Vertical
J3: PropPlug; PinHeader_1x04_P2.54mm_Horizontal
J4: Video Out; CodyRCAJack
J5: Audio Out; CodyRCAJack
JP1: Developer Mode Enable; PinHeader_1x02_P2.54mm_Vertical
R1: 1K; R_Axial_DIN0207_L6.3mm_D2.5mm_P7.62mm_Horizontal
R2: 10K; R_Axial_DIN0207_L6.3mm_D2.5mm_P2.54mm_Vertical
R3: 10K; R_Axial_DIN0207_L6.3mm_D2.5mm_P7.62mm_Horizontal
R4: 270; R_Axial_DIN0207_L6.3mm_D2.5mm_P7.62mm_Horizontal
R5: 560; R_Axial_DIN0207_L6.3mm_D2.5mm_P7.62mm_Horizontal
R6: 1.1K; R_Axial_DIN0207_L6.3mm_D2.5mm_P7.62mm_Horizontal
R7: 220; R_Axial_DIN0207_L6.3mm_D2.5mm_P7.62mm_Horizontal
U1: 74HC541; DIP-20_W7.62mm_Socket
U2: LM2937ET-3.3; TO-220-3_Horizontal_TabDown
U3: P8X32A-D40; DIP-40_W15.24mm_Socket
U4: 24LC256; DIP-8_W7.62mm_Socket
Y1: 5MHz; Crystal_HC49-U_Vertical

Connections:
+3V3: C1.1, C2.1, C3.1, C4.1, C5.1, R1.2, R2.2, R3.2, U1.20 (VCC), U2.3 (VO), U3.12 (VDD), U3.32 (VDD), U4.8 (VCC); also elsewhere on the board
/Propeller, Video, Audio, Power/VIN: J1.1, U2.1 (VI)
A0: U1.2 (A0); also elsewhere on the board
A1: U1.3 (A1); also elsewhere on the board
A2: U1.4 (A2); also elsewhere on the board
A3: U1.5 (A3); also elsewhere on the board
A4: U1.6 (A4); also elsewhere on the board
A5: U1.7 (A5); also elsewhere on the board
A6: U1.8 (A6); also elsewhere on the board
A7: U1.9 (A7); also elsewhere on the board
A8: U3.13 (P8); also elsewhere on the board
A9: U3.14 (P9); also elsewhere on the board
A10: U3.15 (P10); also elsewhere on the board
A11: U3.16 (P11); also elsewhere on the board
A12: U3.17 (P12); also elsewhere on the board
A13: U3.18 (P13); also elsewhere on the board
A14: U3.19 (P14); also elsewhere on the board
A15: U3.20 (P15); also elsewhere on the board
D0: U1.18 (Y0), U3.1 (P0); also elsewhere on the board
D1: U1.17 (Y1), U3.2 (P1); also elsewhere on the board
D2: U1.16 (Y2), U3.3 (P2); also elsewhere on the board
D3: U1.15 (Y3), U3.4 (P3); also elsewhere on the board
D4: U1.14 (Y4), U3.5 (P4); also elsewhere on the board
D5: U1.13 (Y5), U3.6 (P5); also elsewhere on the board
D6: U1.12 (Y6), U3.7 (P6); also elsewhere on the board
D7: U1.11 (Y7), U3.8 (P7); also elsewhere on the board
GND: C1.2, C2.2, C3.2, C4.2, C5.2, C6.2, J1.2, J2.2, J3.4, J4.2 (Ext), J5.2 (Ext), U1.1 (G1), U1.10 (GND), U2.2 (GND), U3.9 (VSS), U3.10 (~BOE), U3.29 (VSS), U4.1 (A0), U4.2 (A1), U4.3 (A2), U4.4 (GND), U4.7 (WP); also elsewhere on the board
unnamed: C6.1, C7.1, R7.1
unnamed: C7.2, J5.1 (In)
unnamed: J2.1, R1.1
unnamed: J3.1, U3.39 (P30)
unnamed: J3.2, U3.40 (P31)
unnamed: J3.3, JP1.2 (B)
unnamed: J4.1 (In), R4.1, R5.1, R6.1
unnamed: JP1.1 (A), R2.1, U3.11 (~RES)
unnamed: R3.1, U3.38 (P29), U4.5 (SDA)
unnamed: R4.2, U3.35 (P26)
unnamed: R5.2, U3.34 (P25)
unnamed: R6.2, U3.33 (P24)
unnamed: R7.2, U3.36 (P27)
unnamed: U1.19 (G2), U3.21 (P16)
unnamed: U3.30 (XI), Y1.1
unnamed: U3.31 (XO), Y1.2
unnamed: U3.37 (P28), U4.6 (SCL)
PHI2: U3.22 (P17); also elsewhere on the board
RWB: U3.24 (P19); also elsewhere on the board
UARTRX: U3.28 (P23); also elsewhere on the board
UARTTX: U3.27 (P22); also elsewhere on the board
~IOSEL: U3.25 (P20); also elsewhere on the board
~RAMSEL: U3.26 (P21); also elsewhere on the board
~RESET: U3.23 (P18); also elsewhere on the board

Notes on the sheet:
Decoupling capacitors (4) on supply lines: 74HC541 (1), P8X32 (2), 24LC256 (1)

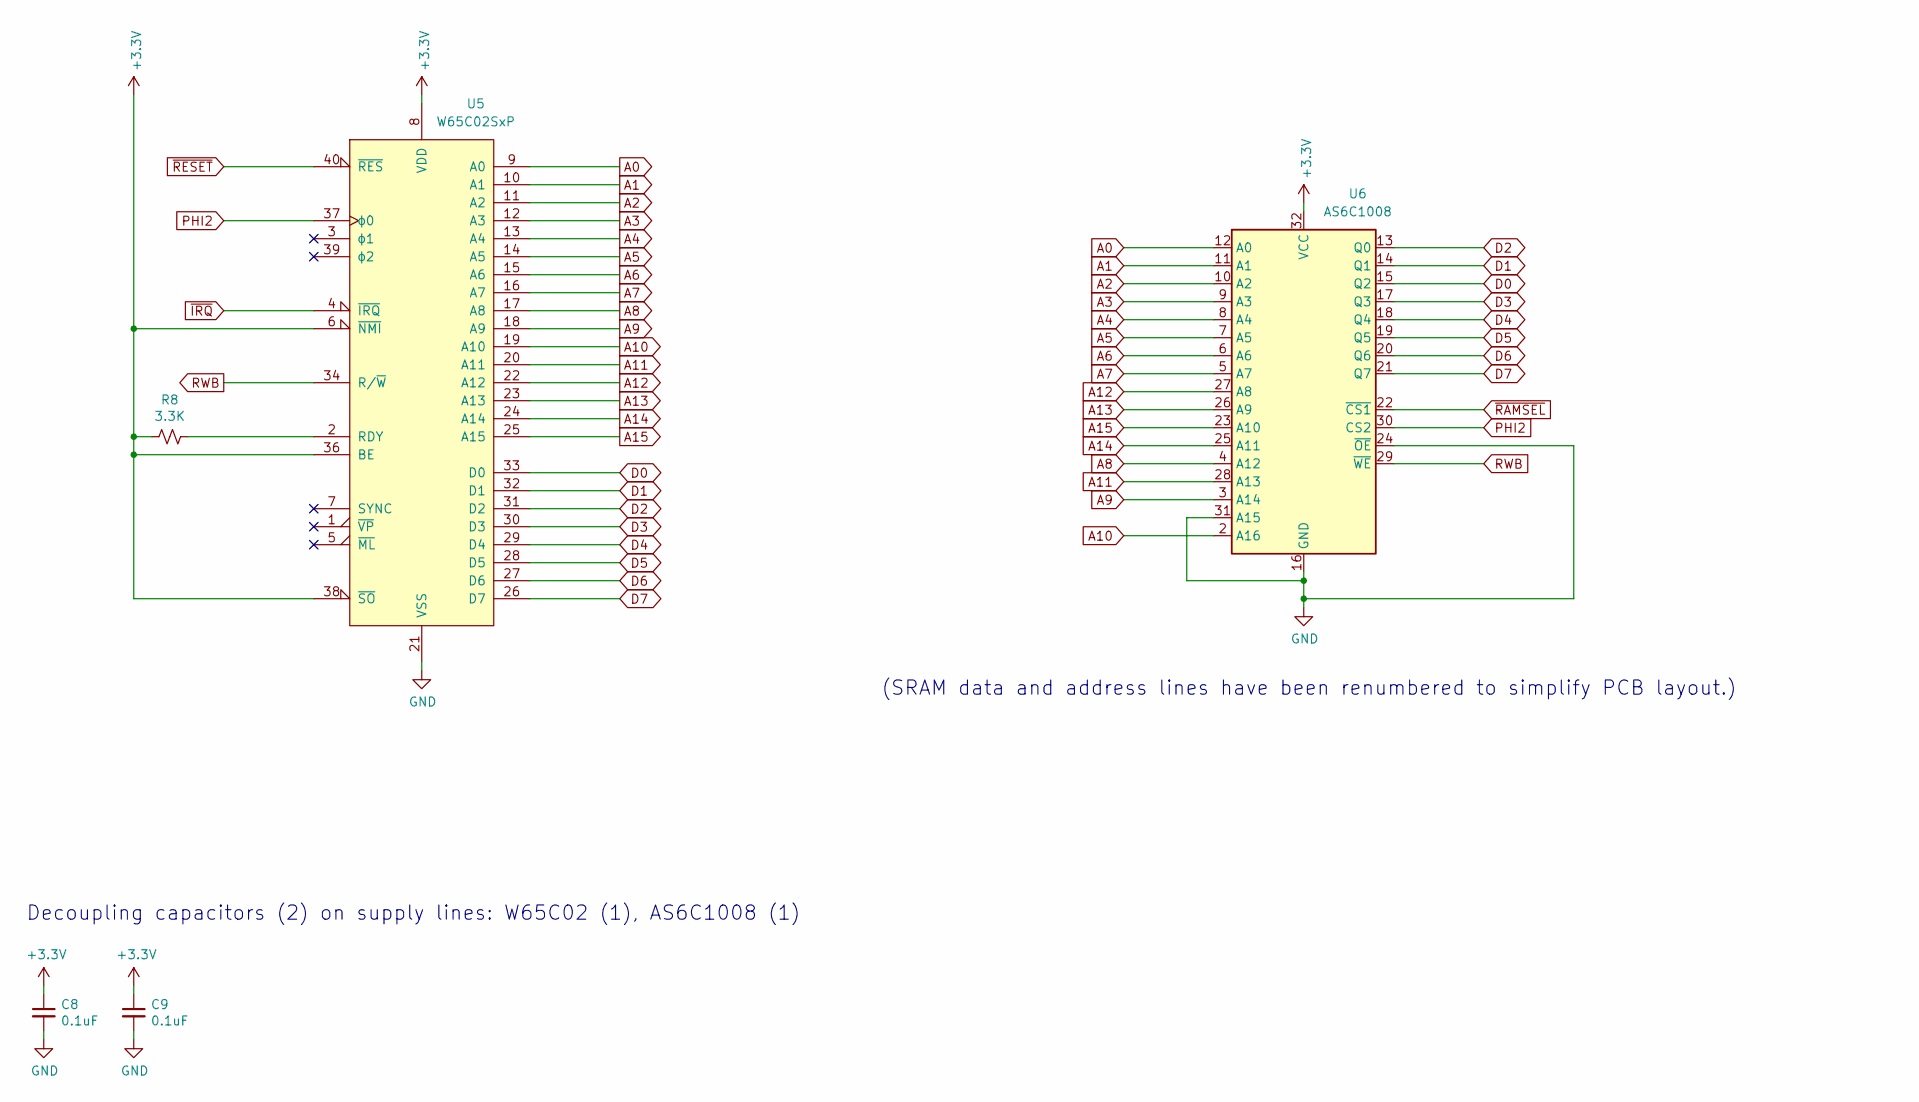
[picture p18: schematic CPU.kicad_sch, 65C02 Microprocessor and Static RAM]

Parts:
C8, C9: 0.1uF; C_Disc_D3.8mm_W2.6mm_P2.50mm
R8: 3.3K; R_Axial_DIN0207_L6.3mm_D2.5mm_P7.62mm_Horizontal
U5: W65C02SxP; DIP-40_W15.24mm_Socket
U6: AS6C1008; DIP-32_W15.24mm_Socket

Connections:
+3V3: C8.1, C9.1, R8.2, U5.6 (~NMI), U5.8 (VDD), U5.36 (BE), U5.38 (~SO), U6.32 (VCC); also elsewhere on the board
A0: U5.9 (A0), U6.12 (A0); also elsewhere on the board
A1: U5.10 (A1), U6.11 (A1); also elsewhere on the board
A2: U5.11 (A2), U6.10 (A2); also elsewhere on the board
A3: U5.12 (A3), U6.9 (A3); also elsewhere on the board
A4: U5.13 (A4), U6.8 (A4); also elsewhere on the board
A5: U5.14 (A5), U6.7 (A5); also elsewhere on the board
A6: U5.15 (A6), U6.6 (A6); also elsewhere on the board
A7: U5.16 (A7), U6.5 (A7); also elsewhere on the board
A8: U5.17 (A8), U6.4 (A12); also elsewhere on the board
A9: U5.18 (A9), U6.3 (A14); also elsewhere on the board
A10: U5.19 (A10), U6.2 (A16); also elsewhere on the board
A11: U5.20 (A11), U6.28 (A13); also elsewhere on the board
A12: U5.22 (A12), U6.27 (A8); also elsewhere on the board
A13: U5.23 (A13), U6.26 (A9); also elsewhere on the board
A14: U5.24 (A14), U6.25 (A11); also elsewhere on the board
A15: U5.25 (A15), U6.23 (A10); also elsewhere on the board
D0: U5.33 (D0), U6.15 (Q2); also elsewhere on the board
D1: U5.32 (D1), U6.14 (Q1); also elsewhere on the board
D2: U5.31 (D2), U6.13 (Q0); also elsewhere on the board
D3: U5.30 (D3), U6.17 (Q3); also elsewhere on the board
D4: U5.29 (D4), U6.18 (Q4); also elsewhere on the board
D5: U5.28 (D5), U6.19 (Q5); also elsewhere on the board
D6: U5.27 (D6), U6.20 (Q6); also elsewhere on the board
D7: U5.26 (D7), U6.21 (Q7); also elsewhere on the board
GND: C8.2, C9.2, U5.21 (VSS), U6.16 (GND), U6.24 (~OE), U6.31 (A15); also elsewhere on the board
unnamed: R8.1, U5.2 (RDY)
PHI2: U5.37 (ϕ0), U6.30 (CS2); also elsewhere on the board
RWB: U5.34 (R/~W), U6.29 (~WE); also elsewhere on the board
~IRQ: U5.4 (~IRQ); also elsewhere on the board
~RAMSEL: U6.22 (~CS1); also elsewhere on the board
~RESET: U5.40 (~RES); also elsewhere on the board

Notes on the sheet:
(SRAM data and address lines have been renumbered to simplify PCB layout.)
Decoupling capacitors (2) on supply lines: W65C02 (1), AS6C1008 (1)

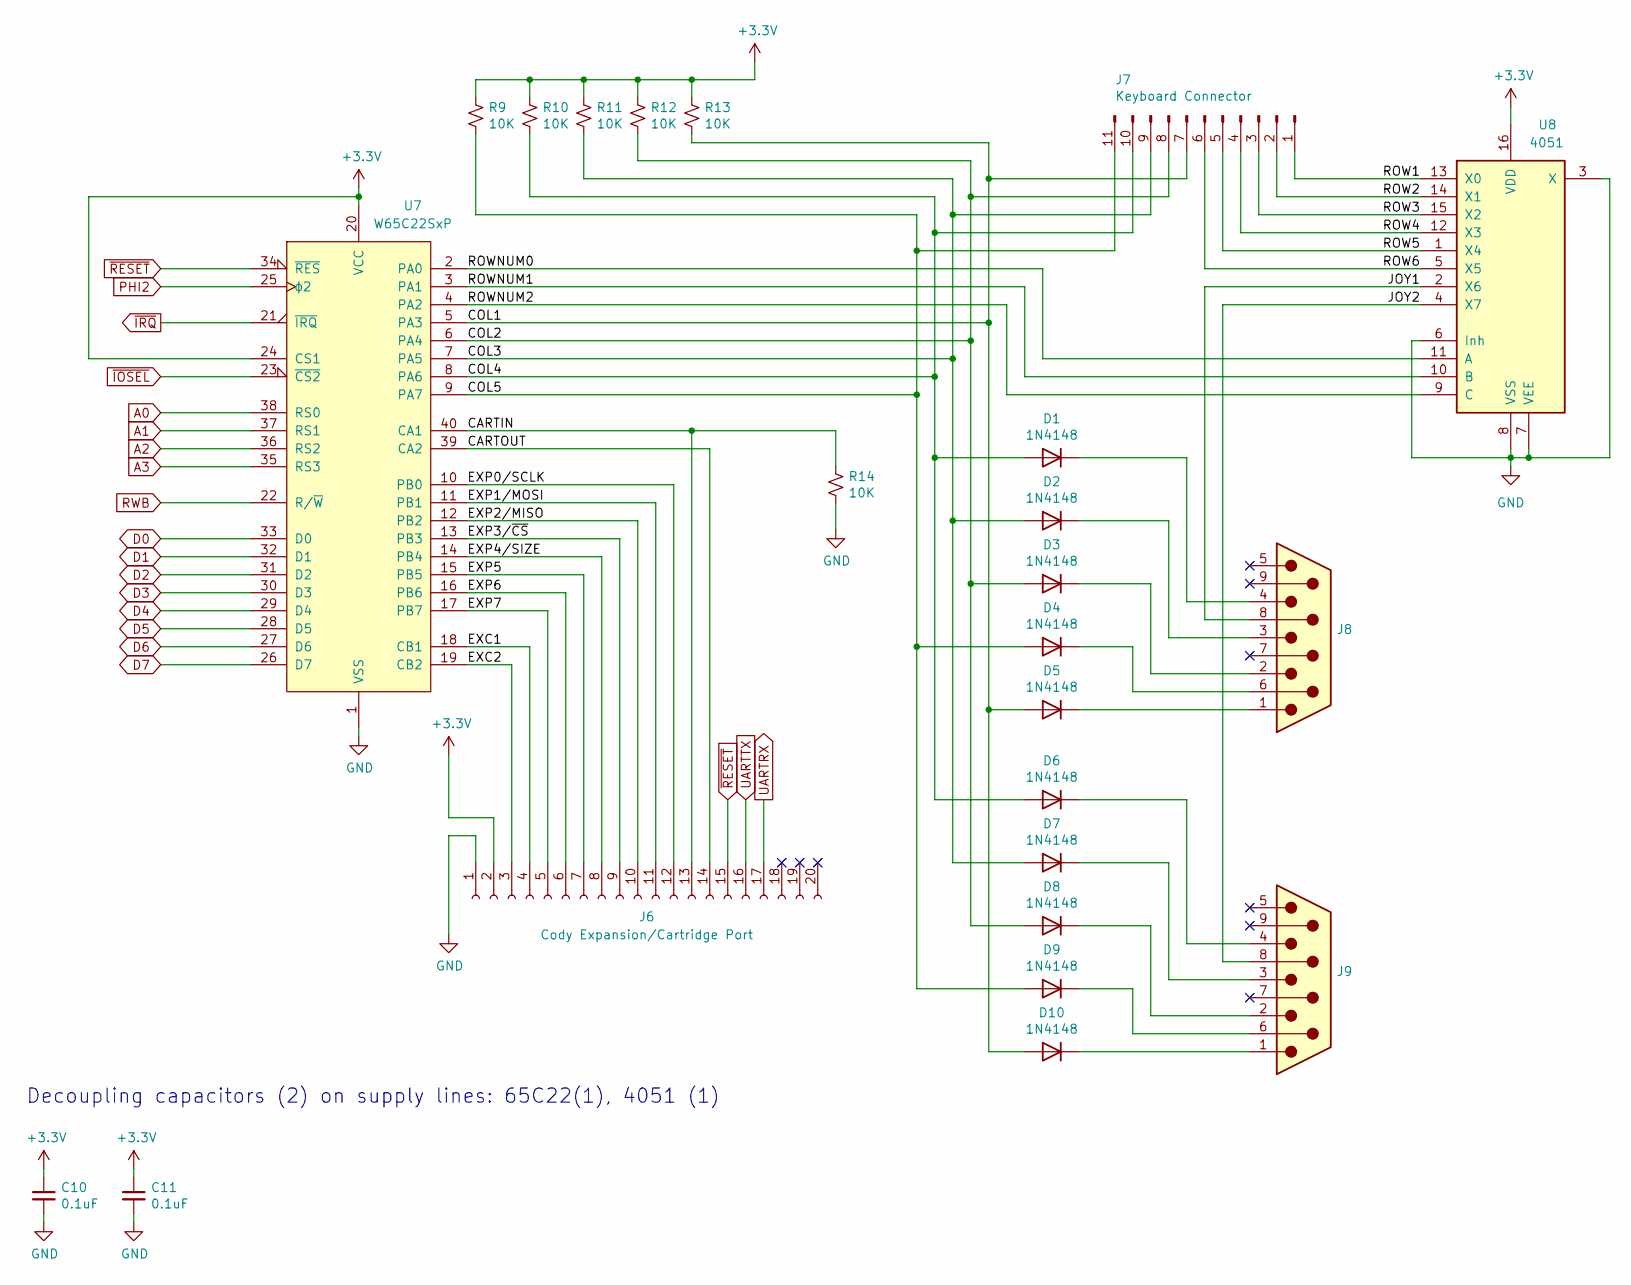
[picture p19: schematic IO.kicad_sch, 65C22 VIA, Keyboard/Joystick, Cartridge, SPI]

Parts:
C10, C11: 0.1uF; C_Disc_D3.8mm_W2.6mm_P2.50mm
D1, D2, D3, D4, D5, D6, D7, D8, D9, D10: 1N4148; D_DO-34_SOD68_P7.62mm_Horizontal
J6: Cody Expansion/Cartridge Port; PinSocket_1x20_P2.54mm_Horizontal
J7: Keyboard Connector; PinHeader_1x11_P2.54mm_Vertical
J8, J9: DSUB-9_Male_Horizontal_P2.77x2.84mm_EdgePinOffset7.70mm_Hou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
R9, R10, R11, R12, R13: 10K; R_Axial_DIN0207_L6.3mm_D2.5mm_P7.62mm_Horizontal
R14: 10K; R_Axial_DIN0207_L6.3mm_D2.5mm_P2.54mm_Vertical
U7: W65C22SxP; DIP-40_W15.24mm_Socket
U8: 4051; DIP-16_W7.62mm_Socket

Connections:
+3V3: C10.1, C11.1, J6.2, R9.2, R10.2, R11.2, R12.2, R13.2, U7.20 (VCC), U7.24 (CS1), U8.16 (VDD); also elsewhere on the board
/65C22 and IO/CARTIN: J6.13, R14.2, U7.40 (CA1)
/65C22 and IO/CARTOUT: J6.14, U7.39 (CA2)
/65C22 and IO/COL1: D5.2 (A), D10.2 (A), J7.7, R13.1, U7.5 (PA3)
/65C22 and IO/COL2: D3.2 (A), D8.2 (A), J7.8, R12.1, U7.6 (PA4)
/65C22 and IO/COL3: D2.2 (A), D7.2 (A), J7.9, R11.1, U7.7 (PA5)
/65C22 and IO/COL4: D1.2 (A), D6.2 (A), J7.10, R10.1, U7.8 (PA6)
/65C22 and IO/COL5: D4.2 (A), D9.2 (A), J7.11, R9.1, U7.9 (PA7)
/65C22 and IO/EXC1: J6.4, U7.18 (CB1)
/65C22 and IO/EXC2: J6.3, U7.19 (CB2)
/65C22 and IO/EXP0/SCLK: J6.12, U7.10 (PB0)
/65C22 and IO/EXP1/MOSI: J6.11, U7.11 (PB1)
/65C22 and IO/EXP2/MISO: J6.10, U7.12 (PB2)
/65C22 and IO/EXP3/~CS: J6.9, U7.13 (PB3)
/65C22 and IO/EXP4/SIZE: J6.8, U7.14 (PB4)
/65C22 and IO/EXP5: J6.7, U7.15 (PB5)
/65C22 and IO/EXP6: J6.6, U7.16 (PB6)
/65C22 and IO/EXP7: J6.5, U7.17 (PB7)
/65C22 and IO/JOY1: J8.8, U8.2 (X6)
/65C22 and IO/JOY2: J9.8, U8.4 (X7)
/65C22 and IO/ROW1: J7.1, U8.13 (X0)
/65C22 and IO/ROW2: J7.2, U8.14 (X1)
/65C22 and IO/ROW3: J7.3, U8.15 (X2)
/65C22 and IO/ROW4: J7.4, U8.12 (X3)
/65C22 and IO/ROW5: J7.5, U8.1 (X4)
/65C22 and IO/ROW6: J7.6, U8.5 (X5)
/65C22 and IO/ROWNUM0: U7.2 (PA0), U8.11 (A)
/65C22 and IO/ROWNUM1: U7.3 (PA1), U8.10 (B)
/65C22 and IO/ROWNUM2: U7.4 (PA2), U8.9 (C)
A0: U7.38 (RS0); also elsewhere on the board
A1: U7.37 (RS1); also elsewhere on the board
A2: U7.36 (RS2); also elsewhere on the board
A3: U7.35 (RS3); also elsewhere on the board
D0: U7.33 (D0); also elsewhere on the board
D1: U7.32 (D1); also elsewhere on the board
D2: U7.31 (D2); also elsewhere on the board
D3: U7.30 (D3); also elsewhere on the board
D4: U7.29 (D4); also elsewhere on the board
D5: U7.28 (D5); also elsewhere on the board
D6: U7.27 (D6); also elsewhere on the board
D7: U7.26 (D7); also elsewhere on the board
GND: C10.2, C11.2, J6.1, R14.1, U7.1 (VSS), U8.3 (X), U8.6 (Inh), U8.7 (VEE), U8.8 (VSS); also elsewhere on the board
unnamed: D1.1 (K), J8.4
unnamed: D2.1 (K), J8.3
unnamed: D3.1 (K), J8.2
unnamed: D4.1 (K), J8.6
unnamed: D5.1 (K), J8.1
unnamed: D6.1 (K), J9.4
unnamed: D7.1 (K), J9.3
unnamed: D8.1 (K), J9.2
unnamed: D9.1 (K), J9.6
unnamed: D10.1 (K), J9.1
PHI2: U7.25 (ϕ2); also elsewhere on the board
RWB: U7.22 (R/~W); also elsewhere on the board
UARTRX: J6.17; also elsewhere on the board
UARTTX: J6.16; also elsewhere on the board
~IOSEL: U7.23 (~CS2); also elsewhere on the board
~IRQ: U7.21 (~IRQ); also elsewhere on the board
~RESET: J6.15, U7.34 (~RES); also elsewhere on the board

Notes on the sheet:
Decoupling capacitors (2) on supply lines: 65C22(1), 4051 (1)

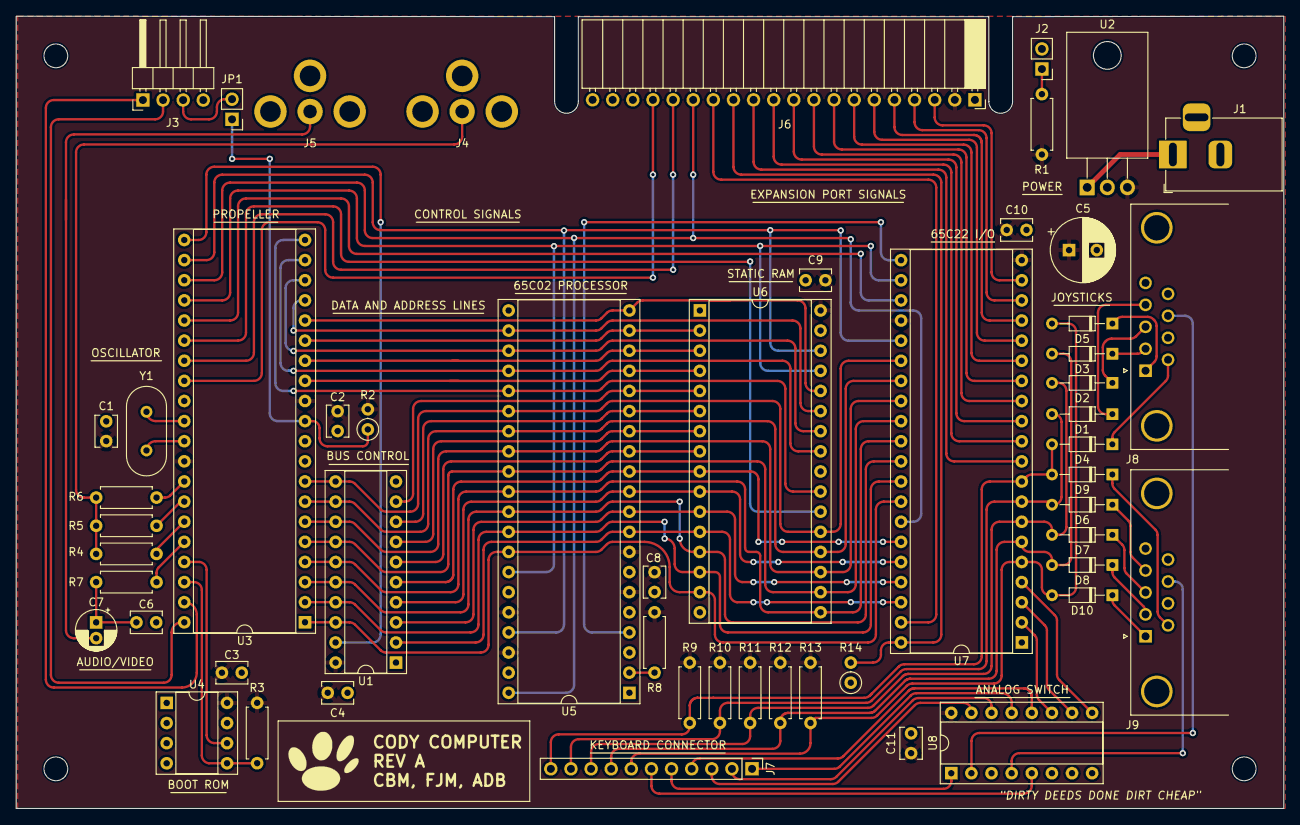
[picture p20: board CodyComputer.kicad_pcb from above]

Board: 2 copper layers, 160.0 x 100.0 mm, 54 parts (0 on the bottom side), 91 nets.

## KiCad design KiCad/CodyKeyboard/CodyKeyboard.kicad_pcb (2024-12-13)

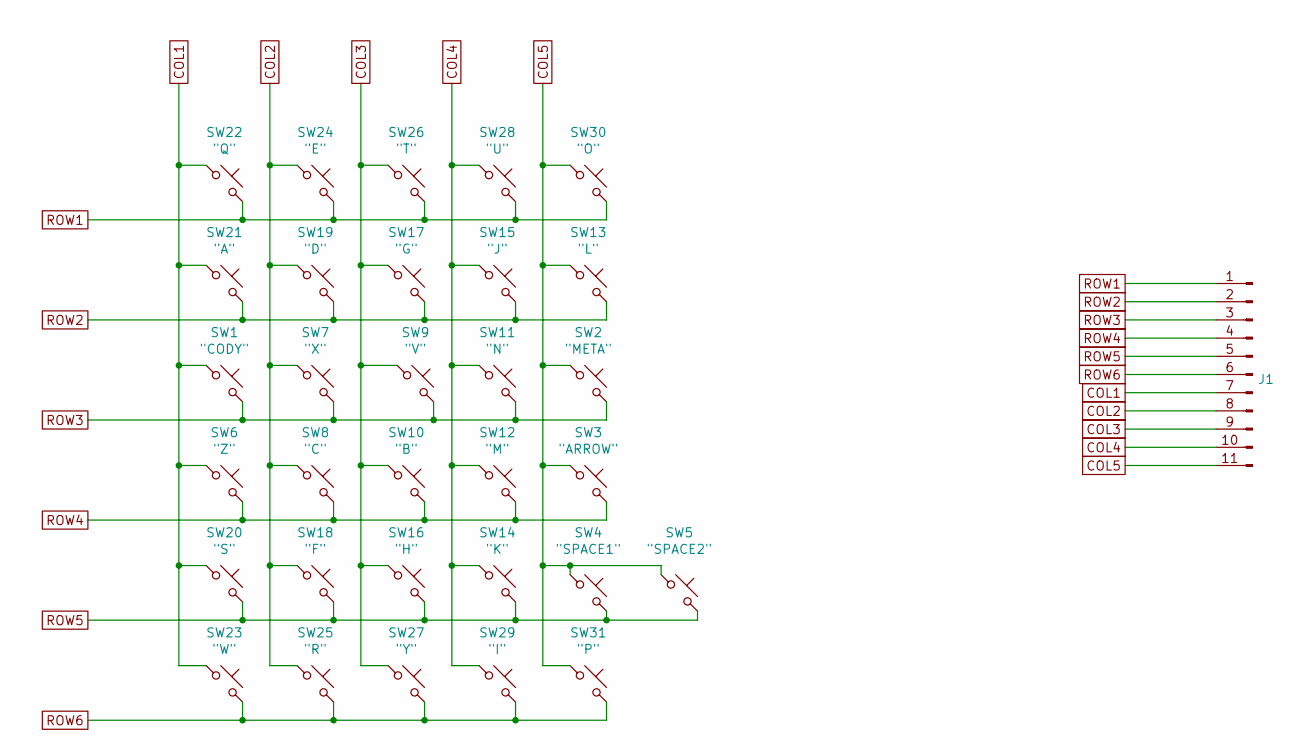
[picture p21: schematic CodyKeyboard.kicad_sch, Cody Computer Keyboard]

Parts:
J1: PinHeader_1x11_P2.54mm_Horizontal
SW1: "CODY"; CodyKeyboardSwitch
SW2: "META"; CodyKeyboardSwitch
SW3: "ARROW"; CodyKeyboardSwitch
SW4: "SPACE1"; CodyKeyboardSwitch
SW5: "SPACE2"; CodyKeyboardSwitch
SW6: "Z"; CodyKeyboardSwitch
SW7: "X"; CodyKeyboardSwitch
SW8: "C"; CodyKeyboardSwitch
SW9: "V"; CodyKeyboardSwitch
SW10: "B"; CodyKeyboardSwitch
SW11: "N"; CodyKeyboardSwitch
SW12: "M"; CodyKeyboardSwitch
SW13: "L"; CodyKeyboardSwitch
SW14: "K"; CodyKeyboardSwitch
SW15: "J"; CodyKeyboardSwitch
SW16: "H"; CodyKeyboardSwitch
SW17: "G"; CodyKeyboardSwitch
SW18: "F"; CodyKeyboardSwitch
SW19: "D"; CodyKeyboardSwitch
SW20: "S"; CodyKeyboardSwitch
SW21: "A"; CodyKeyboardSwitch
SW22: "Q"; CodyKeyboardSwitch
SW23: "W"; CodyKeyboardSwitch
SW24: "E"; CodyKeyboardSwitch
SW25: "R"; CodyKeyboardSwitch
SW26: "T"; CodyKeyboardSwitch
SW27: "Y"; CodyKeyboardSwitch
SW28: "U"; CodyKeyboardSwitch
SW29: "I"; CodyKeyboardSwitch
SW30: "O"; CodyKeyboardSwitch
SW31: "P"; CodyKeyboardSwitch

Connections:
COL1: J1.7, SW1.1, SW6.1, SW20.1, SW21.1, SW22.1, SW23.1
COL2: J1.8, SW7.1, SW8.1, SW18.1, SW19.1, SW24.1, SW25.1
COL3: J1.9, SW9.1, SW10.1, SW16.1, SW17.1, SW26.1, SW27.1
COL4: J1.10, SW11.1, SW12.1, SW14.1, SW15.1, SW28.1, SW29.1
COL5: J1.11, SW2.1, SW3.1, SW4.1, SW5.1, SW13.1, SW30.1, SW31.1
ROW1: J1.1, SW22.2, SW24.2, SW26.2, SW28.2, SW30.2
ROW2: J1.2, SW13.2, SW15.2, SW17.2, SW19.2, SW21.2
ROW3: J1.3, SW1.2, SW2.2, SW7.2, SW9.2, SW11.2
ROW4: J1.4, SW3.2, SW6.2, SW8.2, SW10.2, SW12.2
ROW5: J1.5, SW4.2, SW5.2, SW14.2, SW16.2, SW18.2, SW20.2
ROW6: J1.6, SW23.2, SW25.2, SW27.2, SW29.2, SW31.2

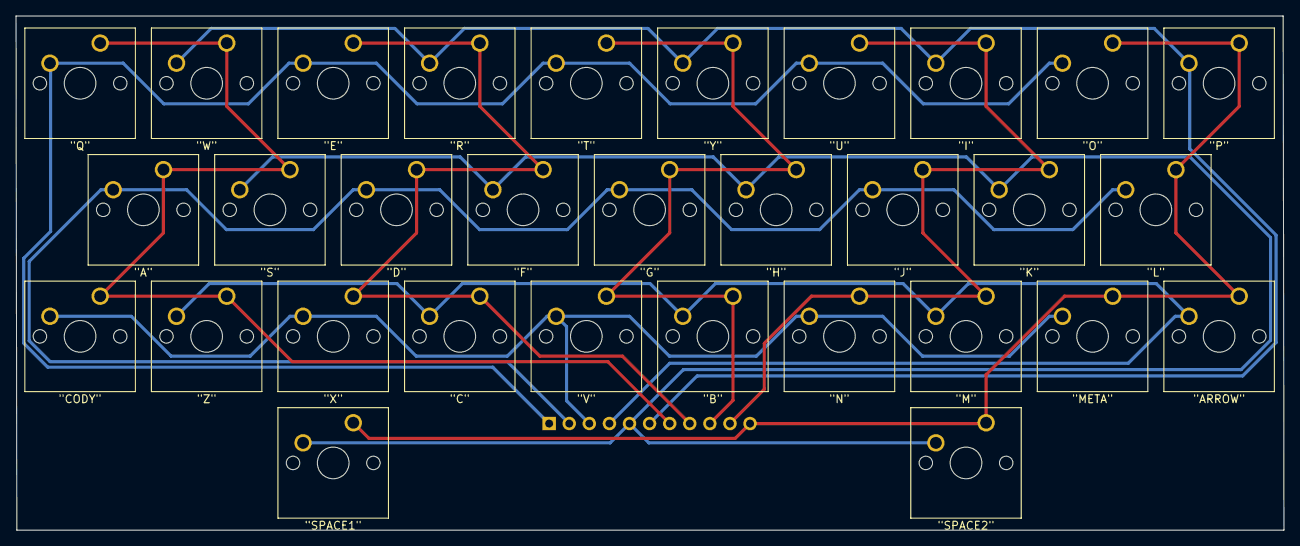
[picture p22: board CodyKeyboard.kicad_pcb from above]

Board: 2 copper layers, 160.3 x 65.0 mm, 32 parts (1 on the bottom side), 11 nets.

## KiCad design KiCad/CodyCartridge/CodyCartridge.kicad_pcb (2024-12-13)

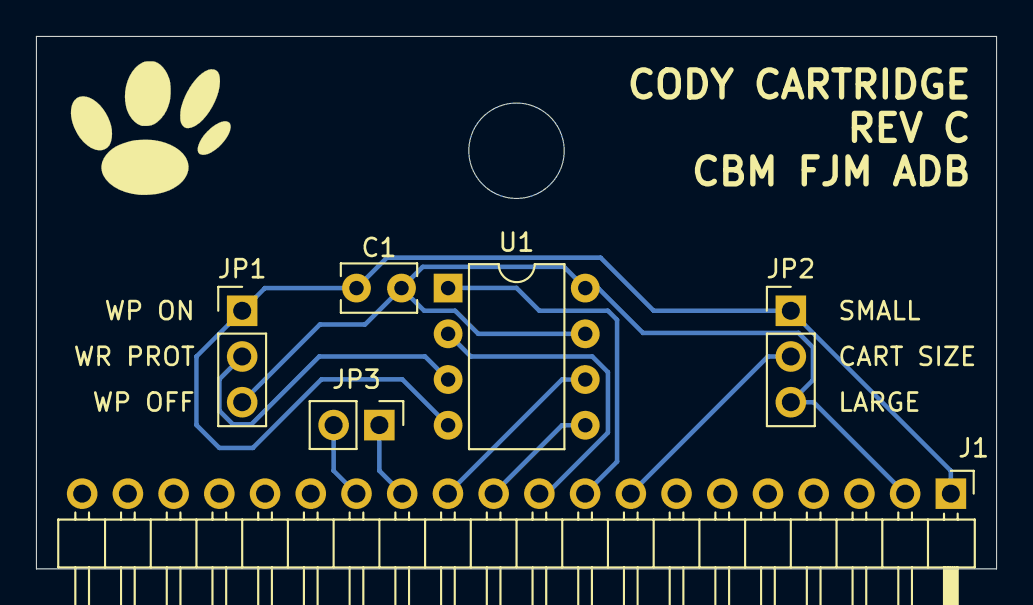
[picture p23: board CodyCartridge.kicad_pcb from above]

Board: 2 copper layers, 53.3 x 29.6 mm, 6 parts (0 on the bottom side), 10 nets.

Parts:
C1: 0.1μF; C_Rect_L4.0mm_W2.5mm_P2.50mm
J1: Cody Expansion Port; PinHeader_1x20_P2.54mm_Horizontal
JP1: Cartridge Write-Protect; PinHeader_1x03_P2.54mm_Vertical
JP2: Cartridge Size; PinHeader_1x03_P2.54mm_Vertical
JP3: Cartridge Detect; PinHeader_1x02_P2.54mm_Vertical
U1: 25LCxxx; DIP-8_W7.62mm

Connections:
unnamed: C1.1, J1.2, JP1.3 (B), JP2.3 (B), U1.7 (~HOLD), U1.8 (VCC)
unnamed: C1.2, J1.1, JP1.1 (A), JP2.1 (A), U1.4 (GND)
unnamed: J1.8, JP2.2 (C)
unnamed: J1.9, U1.1 (~CS)
unnamed: J1.10, U1.2 (MISO)
unnamed: J1.11, U1.5 (MOSI)
unnamed: J1.12, U1.6 (SCK)
unnamed: J1.13, JP3.1 (A)
unnamed: J1.14, JP3.2 (B)
unnamed: JP1.2 (C), U1.3 (~WP)

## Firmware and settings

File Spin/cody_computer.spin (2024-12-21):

'
' cody_computer.spin
' Main Propeller routine for the Cody Computer.
'
' Copyright 2024 Frederick John Milens III, The Cody Computer Developers.
' 
' This program is free software; you can redistribute it and/or
' modify it under the terms of the GNU General Public License
' as published by the Free Software Foundation; either version 3
' of the License, or (at your option) any later version.

' This program is distributed in the hope that it will be useful,
' but WITHOUT ANY WARRANTY; without even the implied warranty of
' MERCHANTABILITY or FITNESS FOR A PARTICULAR PURPOSE.  See the
' GNU General Public License for more details.
'
' You should have received a copy of the GNU General Public License
' along with this program; if not, write to the Free Software
' Foundation, Inc., 51 Franklin Street, Fifth Floor, Boston, MA 02110-1301, USA.
'
' SUMMARY
' 
' Implements the "driver" of the Cody Computer responsible for running the 65C02
' and watching the bus. Also responible for controlling the address buffer, decoding
' 65C22 and RAM addresses, and performing other core operations. Other features
' (including video, audio, and serial communication) are delegated to other cogs
' mapped to the same shared memory area.
' 
CON

  _clkmode = xtal1 + pll16x 
  _xinfreq = 5_000_000

  PIN_ABE       = 16        ' Pin mappings (see below or refer to schematic)
  PIN_PHI       = 17
  PIN_RES       = 18
  PIN_RWB       = 19
  PIN_IOSEL     = 20
  PIN_RAMSEL    = 21
  PIN_AUDIO     = 27

OBJ

    video   : "cody_video.spin"
    audio   : "cody_audio.spin"
    uart    : "cody_uart.spin"

VAR
    
    long stack[128]         ' Reserved stack space for SPIN (provides a safety margin)
    
DAT

memory 
   
    long 0[4096]    ' 16K shared RAM starting at 65C02 address $A000
    long            ' 8K ROM (BASIC, character set) starting at 65C02 address $E000
    FILE "codybasic.bin"

'
' Startup routine for the entire Cody Computer. Launches the audio, video, and
' UART cogs, waits for them to come up, and then replaces the current cog with
' the driver code written in PASM.
'
PUB start
   
    audio.start(@memory)
    uart.start(@memory)
    video.start(@memory)
    
    waitcnt(cnt + 10000)
    coginit(0, @cogmain, @memory)

DAT                     org     0

'
' Entry point for the driver. Calculates addresses based on the pointer to shared
' memory, configures Propeller I/O pins for driving the circuit, and emits the
' reset pulse to start the 65C02. After that it enters into an infinite loop to
' handle the 65C02 bus and respond appropriately to bus signals. 
'
cogmain         mov     memory_ptr, PAR
              
                ' adjust ROM cutoff location with start address of memory
                add     BOUNDARY_ROM, memory_ptr
            
                ' configure the IO pins used for 6502 and bus signals
                mov     OUTA, INIT_OUTA
                mov     DIRA, INIT_DIRA
            
                ' run 65C02 reset sequence of 10 clocks with reset high
                call    #emit_reset
            
                ' dummy read to align our code with hub access windows
                ' before commencing the main loop driving the 6502
                rdbyte  data, addr

'
' Implements a single 65C02 cycle where each instruction has been counted for length,
' including hub operations. This routine will run in an infinite loop once entered,
' driving the 65C02 and decoding bus operations until the system is shut off.
' 
' At a high level, the Propeller drives the 65C02 clock and watches the bus. Depending
' on clock phase the Propeller reads the current address. If the address is within the
' Propeller, it will map the read or write to its shared memory. If the address is not,
' the address is decoded and the appropriate chip selected (SRAM or 65C22 VIA).
' 
' The timing should be completely deterministic (important since our generated clock
' is used for the 65C22's timers, which would otherwise drift) after the preceding
' rdbyte syncs up with the hub.
' 
cycle                        
                ' Begin the main 6502 loop by bringing phi low to end
                ' the previous cycle, then reset the OUTA/DIRA config.
                ' 
                ' Once we've reset our state to begin the next cycle,
                ' read from the inputs and determine what we need to do.
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

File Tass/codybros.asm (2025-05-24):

;
; codybros.asm
; A scrolling game demo inspired by Super Mario Bros and Great Giana Sisters.
;
; Copyright 2024 Frederick John Milens III, The Cody Computer Developers.
;
; This program is free software; you can redistribute it and/or
; modify it under the terms of the GNU General Public License
; as published by the Free Software Foundation; either version 3
; of the License, or (at your option) any later version.
;
; This program is distributed in the hope that it will be useful,
; but WITHOUT ANY WARRANTY; without even the implied warranty of
; MERCHANTABILITY or FITNESS FOR A PARTICULAR PURPOSE.  See the
; GNU General Public License for more details.
;
; You should have received a copy of the GNU General Public License
; along with this program; if not, write to the Free Software
; Foundation, Inc., 51 Franklin Street, Fifth Floor, Boston, MA 02110-1301, USA.
;
; This is not a full game, but it showcases many of the Cody Computer's game
; features. A Pomeranian (in sprite form) can smoothly walk back and forth in
; a game world when the joystick is moved left or right. When the joystick is
; moved up, the Pomeranian barks. When the joystick is moved down, the Pomeranian
; changes outfits. The fire button exits the demo.
;
; To assemble using 64TASS run the following:
;
;   64tass --mw65c02 --nostart -o codybros.bin codybros.asm
;
ADDR      = $0300               ; The actual loading address of the program

SCRRAM1   = $A000               ; Screen memory locations for double-buffering
SCRRAM2   = $A400

COLRAM1   = $A800               ; Color memory locations for double-buffering
COLRAM2   = $AC00

SPRITES   = $B000               ; Sprite memory locations

VIA_BASE  = $9F00               ; VIA base address and register locations
VIA_IORB  = VIA_BASE+$0
VIA_IORA  = VIA_BASE+$1
VIA_DDRB  = VIA_BASE+$2
VIA_DDRA  = VIA_BASE+$3
VIA_T1CL  = VIA_BASE+$4
VIA_T1CH  = VIA_BASE+$5
VIA_SR    = VIA_BASE+$A
VIA_ACR   = VIA_BASE+$B
VIA_PCR   = VIA_BASE+$C
VIA_IFR   = VIA_BASE+$D
VIA_IER   = VIA_BASE+$E

VID_BLNK  = $D000               ; Video blanking status register
VID_CNTL  = $D001               ; Video control register
VID_COLR  = $D002               ; Video color register
VID_BPTR  = $D003               ; Video base pointer register
VID_SCRL  = $D004               ; Video scroll register
VID_SCRC  = $D005               ; Video screen common colors register
VID_SPRC  = $D006               ; Video sprite control register

SPR0_X    = $D080               ; Sprite X coordinate
SPR0_Y    = $D081               ; Sprite Y coordinate
SPR0_COL  = $D082               ; Sprite color
SPR0_PTR  = $D083               ; Sprite base pointer

SID_BASE  = $D400               ; SID registers (mostly for voice 1)
SID_V1FL  = SID_BASE+0
SID_V1FH  = SID_BASE+1
SID_V1PL  = SID_BASE+2
SID_V1PH  = SID_BASE+3
SID_V1CT  = SID_BASE+4
SID_V1AD  = SID_BASE+5
SID_V1SR  = SID_BASE+6
SID_FVOL  = SID_BASE+24

PLAYERX   = $D0                 ; Player coordinates
PLAYERY   = $D1

CORNERX   = $D2                 ; Screen top-left corner coordinates
CORNERY   = $D3

MAPPTR    = $D4                 ; Memory pointers for drawing the screen
SCRPTR    = $D6
COLPTR    = $D8

BUFFLAG   = $DA                 ; Flag indicating what buffer is being used
FWDREV    = $DB                 ; Flag indicating player direction (forward or reverse)

TEMP      = $DC                 ; Temporary variable

; Program header for Cody Basic's loader (needs to be first)

.WORD ADDR                      ; Starting address (just like KIM-1, Commodore, etc.)
.WORD (ADDR + LAST - MAIN - 1)  ; Ending address (so we know when we're done loading)

; The actual program goes below here

.LOGICAL    ADDR                ; The actual program gets loaded at ADDR

;
; MAIN
;
; The starting point of the demo. Performs the necessary setup before the demo runs.
;
MAIN        STZ PLAYERX         ; Reset player position
            LDA #183
            STA PLAYERY

            STZ FWDREV          ; Player moving forward by default
            
            STZ BUFFLAG         ; Clear double buffer flag
            
            LDA #$07            ; Set VIA data direction register A to 00000111 (pins 0-2 outputs, pins 3-7 inputs)     
            STA VIA_DDRA

            LDA #$06            ; Set VIA to read joystick 1
            STA VIA_IORA

            LDA #$01            ; Sprite bank 0, white as common color
            STA VID_SPRC
            
            LDA VID_COLR        ; Set border color to black
            AND #$F0
            STA VID_COLR

            LDA #$E0            ; Store shared colors (light blue and black)
            STA VID_SCRC
  
            LDA #$04            ; Enable horizontal scrolling
            STA VID_CNTL

            LDX #0              ; Copy game map tiles into character memory
_COPYCHAR   LDA CHARDATA,X
            STA $C800,X
            INX
            CPX #80
            BNE _COPYCHAR

            LDX #0              ; Copy sprite data into video memory
_COPYSPRT   LDA SPRITEDATA,X
            STA SPRITES,X
            INX
            CPX #255
            BNE _COPYSPRT
            
            LDA #$D8            ; Initial sprite color
            STA SPR0_COL

;
; LOOP
;
; Main loop of the CODYBROS demo. Control drops through here after setup
; and jumps back here at the end of every game loop.
;
LOOP        LDA PLAYERX         ; Calculate coarse scroll position
            LSR A
            LSR A
            
            CMP #21
            BCC _TOOLO
            
            CMP #47
            BCS _TOOHI
            
            SEC
            SBC #21
            STA CORNERX
            
            BRA _DRAW
            
_TOOLO      STZ CORNERX
            BRA _DRAW
            
_TOOHI      LDA #26
            STA CORNERX
            BRA _DRAW
            
_DRAW       JSR DRAWSCRN        ; Draw the screen and sprite
            JSR DRAWSPRT
            
            LDA VIA_IORA        ; Read joystick
            LSR A
            LSR A
            LSR A
            
            BIT #16             ; Fire button?
            BEQ _FIRE
            
            BIT #8              ; Joystick right?
            BEQ _RIGHT
            
            BIT #4              ; Joystick left?
            BEQ _LEFT

            BIT #2              ; Joystick down to swap colors?
            BEQ SWAPCOLOR
            
            BIT #1              ; Joystick up to bark?
            BEQ BARK
            
            BRA LOOP
            
_FIRE       RTS                 ; Exit on fire button

_LEFT       LDA #1              ; Move left
            STA FWDREV
            
            LDA PLAYERX
            BEQ _NEXT
            
            DEC PLAYERX
            BRA _NEXT
            
_RIGHT      STZ FWDREV          ; Move right

            LDA PLAYERX
            CMP #232
            BEQ _NEXT
            
            INC PLAYERX
            
_NEXT       JMP LOOP
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

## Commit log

2024-12-13 Copy KiCad projects into repository
    [CPU.kicad_sch, CodyCartridge.kicad_pcb, CodyCartridge.kicad_sch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]
2024-12-14 Add OpenSCAD files and supporting SVG files.
    [Cartridge.scad, Case.scad, Keyboard.scad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]
2024-12-14 Add STL files generated from OpenSCAD
    [CartridgeBottom.stl, CartridgeTop.stl, CaseBadge.stl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]
2024-12-17 Add correct license headers before release.
    [Cartridge.scad, Case.scad, Keyboard.scad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]
2024-12-21 Add Propeller .spin files for firmware
2024-12-21 Add 64tass assembly files for Cody BASIC and demos
2024-12-24 Add exported PDF schematics
    [CodyKeyboard.kicad_sch, IO.kicad_sch]
2024-12-26 Add Propeller firmware and assembly example for bitmap mode
2024-12-26 Fix for resetting interrupts on warm reset
    [codybasic.asm]
2025-03-16 Refactor initialization and binary program load to avoid cartridge loops (#6)
    [codybasic.asm]
2025-03-30 Fix typos in comments
    [codybasic.asm]
2025-03-31 Fix video corruption when switching back from hires to lores (#17)
2025-04-16 Add new tokenizer variable to avoid clobbering SYS_A (#22)
    [codybasic.asm]
2025-04-17 Cody BASIC tokenizer fixes for AA/AB and REM (#26)
    [codybasic.asm]
2025-05-24 Fix 'skip' at right side of scroll (#29)
    [codybros.asm]
